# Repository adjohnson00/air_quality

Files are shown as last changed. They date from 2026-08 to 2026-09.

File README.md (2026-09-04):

# Air quality monitor

A local, battery-powered PM2.5 monitor for fire season in the Boise / Meridian, Idaho area. It sits on a shelf or windowsill, reads wildfire smoke from a Plantower laser sensor, and shows **US EPA AQI** on a sunlight-readable e-ink screen. There is no phone app and no cloud — the display is the product.

Summer haze here is usually fine particles from regional fires, not ozone or traffic. The number that matters is **PM2.5**. This build tracks that, plus PM1.0 / PM10 and particle counts, then sleeps so a small LiPo lasts days instead of hours.

**Approximate parts cost: ~$100** (Adafruit list prices, August 2026).

| [Hardware](#hardware) | [How it works](#how-it-works) | [Firmware](#firmware) |
| --- | --- | --- |

## Why this stack

- **Local.** Works during a power-adjacent smoke week without Wi‑Fi, Adafruit IO, or a phone.
- **Readable outdoors.** E-ink stays up with the power off and is usable in daylight, unlike a tiny OLED.
- **Low power.** The sensor’s fan draws ~180 mA from the battery while running. The firmware warms it up, takes a median of three samples, then cuts power and deep-sleeps.
- **Mostly plug-and-play.** Feather + FeatherWing stack, STEMMA QT for the sensor, LiPo that tucks under the headers.

Indoor / porch is the v1 goal. A sealed outdoor box would starve the laser sensor of air.

## Hardware

All parts are sold by Adafruit. The STEMMA cable is the **100 mm** length — long enough to exit the Feather / wing sandwich and leave the sensor sitting beside the stack with its vents open.

| Qty | Part | Adafruit | Price |
| ---: | --- | ---: | ---: |
| 1 | [FeatherS3\[D\] ESP32-S3](https://www.adafruit.com/product/6399) (Unexpected Maker) | 6399 | $24.95 |
| 1 | [2.9" grayscale eInk FeatherWing](https://www.adafruit.com/product/4777) (SSD1680) | 4777 | $22.50 |
| 1 | [PMSA003I air quality breakout](https://www.adafruit.com/product/4632) | 4632 | $44.95 |
| 1 | [STEMMA QT / Qwiic cable, 100 mm](https://www.adafruit.com/product/4210) | 4210 | $0.95 |
| 1 | [400 mAh LiPo, Feather-sized](https://www.adafruit.com/product/3898) | 3898 | $6.95 |
|  | **Total** |  | **$100.30** |

Prices are Adafruit’s single-unit list. Shipping, tax, and a USB-C data cable are extra.

### FeatherS3[D] — brains and power

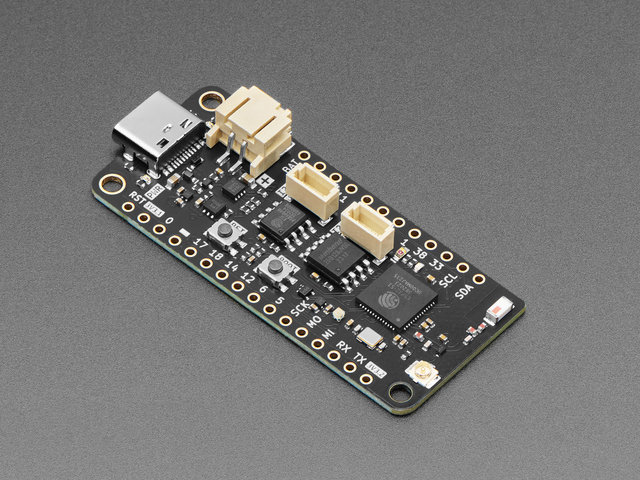
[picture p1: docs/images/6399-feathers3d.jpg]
FeatherS3[D] ESP32-S3 (https://www.adafruit.com/product/6399)


[Adafruit #6399](https://www.adafruit.com/product/6399) · [docs](docs/6399-feathers3d/)

Unexpected Maker’s ESP32-S3 Feather. Dual 240 MHz cores, 16 MB flash, 8 MB PSRAM, USB-C, LiPo charging, and a MAX17048 fuel gauge. Two STEMMA QT ports: **I2C1** stays up in deep sleep (fuel gauge), **I2C2** is on LDO2 so the air sensor can be powered down. The 400 mAh cell sits in the header well under the wing.

### 2.9" grayscale eInk FeatherWing — the screen

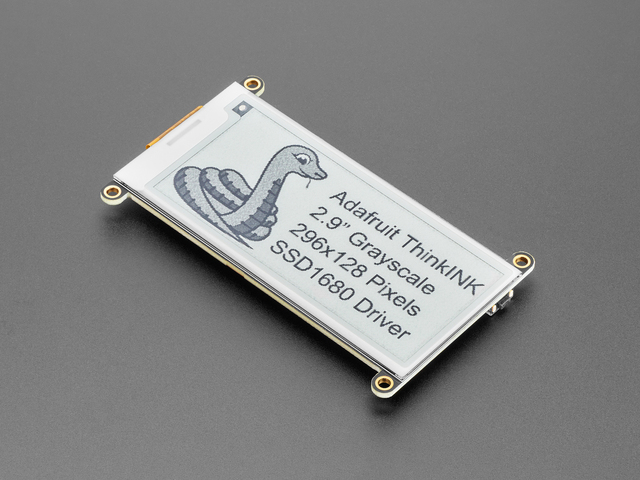
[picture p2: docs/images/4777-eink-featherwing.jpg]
2.9" grayscale eInk FeatherWing (https://www.adafruit.com/product/4777)


[Adafruit #4777](https://www.adafruit.com/product/4777) · [docs](docs/4777-eink-featherwing/)

296×128, four gray levels, SSD1680 (not the old IL0373). Image stays with the power off. On USB the firmware samples every 30 seconds and only refreshes the panel when the numbers change. Three buttons on the **back** of the wing (left to right from the back):

- **A** — force a sample now
- **B** — flip between the AQI card and particle-count bins immediately (press B again to go back)
- **C** — BLE pairing window (hold ~1.5 s to unpair)
- **Reset** — reboots the Feather

### PMSA003I — the smoke sensor

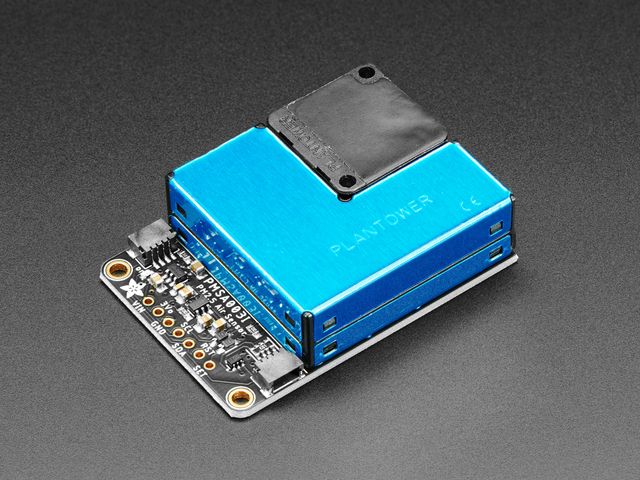
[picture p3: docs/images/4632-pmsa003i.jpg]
PMSA003I air quality breakout (https://www.adafruit.com/product/4632)


[Adafruit #4632](https://www.adafruit.com/product/4632) · [docs](docs/4632-pmsa003i/)

Plantower laser scatter module on a STEMMA QT breakout (I2C `0x12`). Reports PM1.0 / PM2.5 / PM10 and counts from 0.3–10 µm. The breakout boosts 3.3 V up to the 5 V the fan and laser need. This is a hobby sensor, not an FEM — treat it as a trend next to AirNow / PurpleAir, not a regulatory number.

### STEMMA QT cable, 100 mm

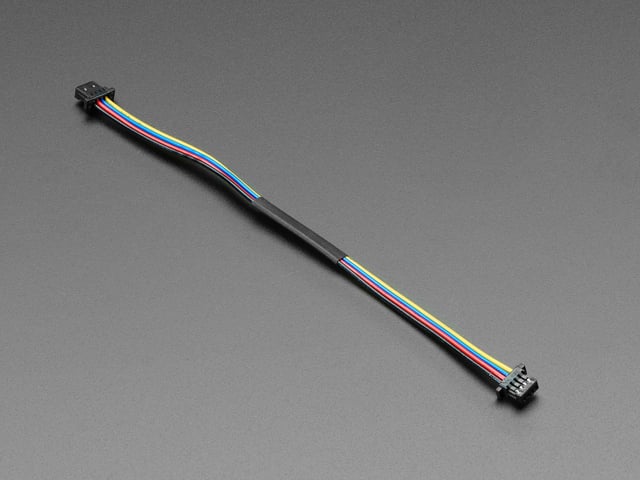
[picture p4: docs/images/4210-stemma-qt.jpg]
STEMMA QT 100 mm cable (https://www.adafruit.com/product/4210)


[Adafruit #4210](https://www.adafruit.com/product/4210) · [docs](docs/4210-stemma-qt-100mm/)

4-pin JST-SH, both ends the same. Plug it into **I2C2 (near USB) before stacking the wing** — that jack is not on the long header. 100 mm is long enough to route out the battery gap and park the sensor beside the stack.

### 400 mAh LiPo

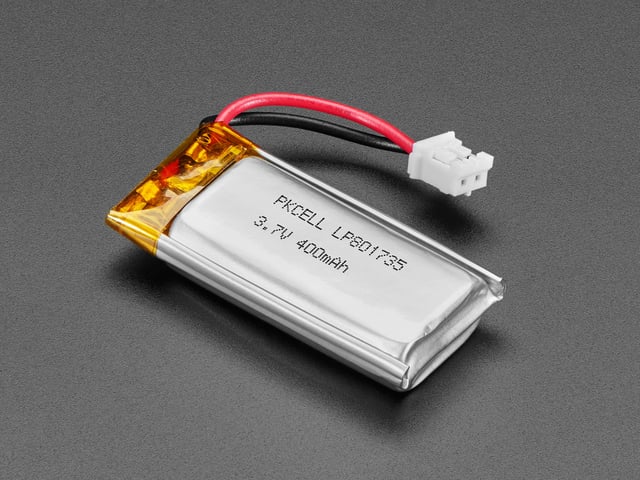
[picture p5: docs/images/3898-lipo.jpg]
400 mAh Feather LiPo (https://www.adafruit.com/product/3898)


[Adafruit #3898](https://www.adafruit.com/product/3898) · [docs](docs/3898-lipo-400mah/)

3.7 V, Feather-sized, 25 mm JST-PH. Charges from the Feather’s USB-C. A full cell is about **4.2 V**. With USB and no pack, the charger node floats ~4.0–4.3 V and SOC can read over 100% — the firmware shows `USB no batt` instead.

You do **not** need to leave USB + battery plugged in for the gauge to work. Powering down and unplugging the cell when idle is the right thing. Next boot, the MAX17048 estimates % from open-circuit voltage (quick-start). That is plenty for this display. A full charge/discharge “learn” cycle only tightens it; it is optional and not worth leaving the project on the charger unused.

At 15-minute samples the pack should last on the order of 3–5 days. Charge only via the Feather, and don’t puncture or bend it.

## How it works

Every sample the Feather enables **LDO2** (the 3.3 V rail on STEMMA I2C2), waits ~15 s for the PMSA003I fan, reads three frames, and keeps the median. If the sample interval is under 60 s (USB default 30 s), LDO2 stays on so you are not paying warmup every time. At 5 minutes or the 15-minute battery interval, LDO2 drops between reads and the sensor is fully off. PM2.5 (environmental) is converted with the **2024 US EPA AQI breakpoints** — same scale AirNow and Idaho DEQ use — as an instantaneous value, not 24-hour NowCast.

To sleep the sensor on USB too, set `USB_SAMPLE_INTERVAL_S = 300` in `settings.toml` (5 minutes).

The 2.9" card shows a large AQI number and category, a 4-gray bar, then PM1.0 / PM2.5 / PM10 in µg/m³ plus battery and USB status.

| Power | Sample interval | What it does |
| --- | --- | --- |
| USB-C | 60 seconds | Stays awake; LDO2 off between samples |
| Battery | 60 seconds, 5 s warmup | Sleeps between samples (`SLEEP_MODE`); ~8–13% sensor duty |
| Cell ≤ 3.2 V | Halt | LOW BATT card, **deep** sleep until USB (or 1 h recheck) |

Wi-Fi stays off. Bluetooth is off at boot and in sleep. The advertised name is always **`AQ-monitor`**. Press **C** to open a pairing window. A successful authorized `GET` (see `BLE_PIN`) marks the phone as paired; then the board advertises briefly on a schedule so you can pull the log without pressing C. Long-press **C** to unpair. Periodic advertising costs pack life — set `BLE_PERIODIC_S = 0` to advertise only after samples / C.

`SLEEP_MODE` in `settings.toml`:

- `"deep"` (default) — lowest current; `code.py` restarts each wake
- `"light"` — CPU paused, RAM kept, faster wake, more sleep current (tens of mA vs µA)
- `"no"` — CPU stays awake; LDO2/sensor on only for each sample (stays on if the interval is under 30 s)
- `"full"` — CPU and PMSA003I/LDO2 stay on

Each sample appends one row to `CIRCUITPY/data/voltN.csv` (voltage, %, USB, PM1/2.5/10, particle bins). A new number is used on each power-up / USB reload; older files are kept. Copy `data/` off the drive into this repo’s `data/` folder. Set `VOLTAGE_LOG = 0` to disable.

CircuitPython cannot write CIRCUITPY while the Mac has it mounted as a normal disk. `boot.py` remounts the drive **MCU-writable** (Finder shows it read-only — you can still copy logs off). **Hold A at reset** when you need to copy firmware onto the board.

## Docs in this repo

- [docs/firmware-loop.html](docs/firmware-loop.html) — how the main loop, sensing, and BLE fit together (open in a browser)
- [docs/project.md](docs/project.md) — original BOM notes
- [docs/build-plan.md](docs/build-plan.md) — pin map, power budget, firmware phases
- [hardware/assembly.md](hardware/assembly.md) — how to stack the boards
- [hardware/enclosure/](hardware/enclosure/) — 3D-printed case, rev 2 (1" stack, battery cage, RP-SMA, split airflow)
- [docs/](docs/) — datasheets and Adafruit learn guides

## Firmware

CircuitPython on the FeatherS3[D]. Source is in [`firmware/`](firmware/).

### Libraries

With the board mounted as `CIRCUITPY`:

```bash
pip install circup
circup install adafruit_pm25 adafruit_epd adafruit_max1704x adafruit_register neopixel adafruit_ble
```

Copy `firmware/font5x8.bin` to the root of `CIRCUITPY`. The e-ink text routines need it.

### Install

1. Assemble the stack ([hardware/assembly.md](hardware/assembly.md)).
2. Copy `firmware/bringup.py` to `CIRCUITPY/code.py` and confirm I2C addresses in the serial console (`0x36` on I2C1, `0x12` on I2C2).
3. Copy the rest of `firmware/` onto `CIRCUITPY` (`code.py`, the `.py` modules, `settings.toml`, `font5x8.bin`).
4. The board resets and draws the AQI card.

### Tests (no hardware)

```bash
python3 -m unittest tests.test_aqi tests.test_battery tests.test_vlog tests.test_ble_xfer
```

### BLE log dump (iPhone)

Uses [Bluefruit LE Connect](https://learn.adafruit.com/bluefruit-le-connect) (central mode).

1. `circup install adafruit_ble` (hold **A** at reset to copy files). Without that library, C shows `FAIL` on the card.
2. Press **C** anytime, including during sensor warmup (the 30 s wait runs in the main loop, so buttons and BLE still work). Footer shows `PAIR`. Connect to **`AQ-monitor`**, open **UART**, send `GET`. The UART session stays up until the phone disconnects; the board only polls `connected`. After a successful GET it stays awake and advertising (sensor/LDO2 off between samples) so you can reconnect without pressing C. Long-press **C** to unpair and return to `SLEEP_MODE`.
3. Send `GET` (or `GET yourpin` if `BLE_PIN` is set). Wait until `# AQ END` — a long log takes tens of seconds (20-byte BLE notifies). Copy after that; missing commas or a file that stops mid-line means it was still sending.
4. After a successful GET, the board can advertise on a schedule so you can reconnect without pressing C. Long-press **C** to unpair. Keep UART in the foreground.

Do not pair the board in iOS Settings. USB copy of `/data/` is still the bulk path. Set `BLE_PIN` on the device only (not in git) if you do not want a nearby phone to dump the log with a plain `GET`.

The FeatherS3[D] has an onboard 3D antenna **and** a u.FL jack, selected by GPIO41. Firmware drives that pin **low** so the onboard antenna is used (`BLE_ANTENNA = "internal"`). A floating switch can dump TX into the empty u.FL and show up on the phone as about **−95 dBm**. Advertising TX power is `BLE_TX_POWER` (default **9 dBm**); CircuitPython’s `BLERadio` helper otherwise always advertises at 0 dBm. You do not need an external antenna yet. If RSSI stays in the −90s after a copy/reset, check that nothing metal covers the 3D antenna; then try `BLE_TX_POWER = 20`. Only then set `BLE_ANTENNA = "external"` with a 2.4 GHz whip on the u.FL — transmitting into an open u.FL can stress the PA.

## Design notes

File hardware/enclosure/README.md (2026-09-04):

# 3D-printed enclosure (rev 2)

Two-piece FDM case. Display faces up. RP-SMA antenna bulkhead on the **left**. PMSA003I on the **floor** to the right, 2" axis away from the display. I/O channels stay at the **top** of the display. **No USB hole** — the Feather’s USB-C faces the AQI bay; plug in with the lid off.

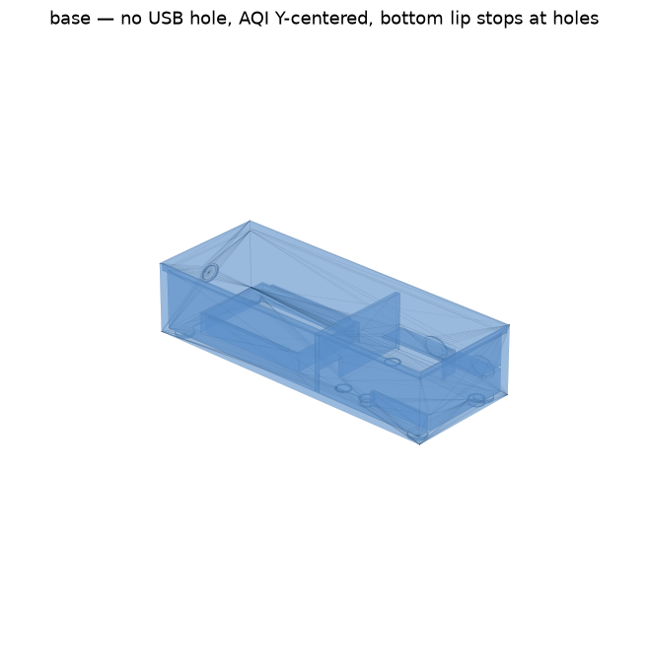
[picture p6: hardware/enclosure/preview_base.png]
Base


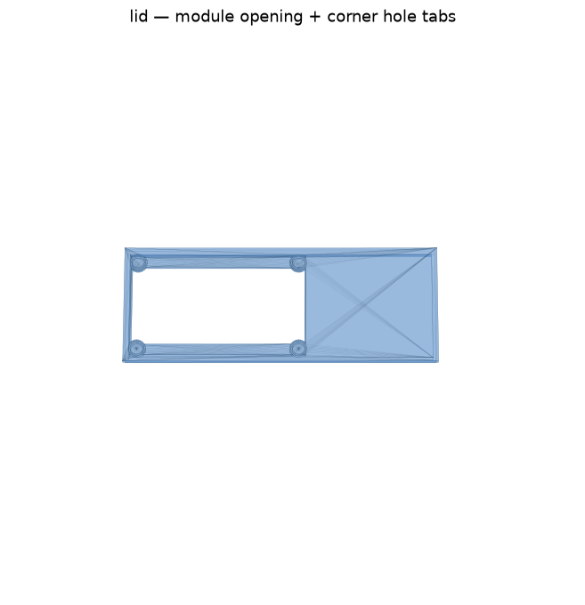
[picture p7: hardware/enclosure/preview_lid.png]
Lid


Outside is about **145 × 56 × 45 mm**.

```
  TOP (+Y)     intake ○ | ○ exhaust     (divider 7/8" from the far end)
               ─────────┴─────────
  LEFT (-X)    [RP-SMA]  [ 2.9" eInk ]  [ PMSA003I, Y-centered on display ]
  BOTTOM (-Y)  closed; AQI lip stops short of the two bottom holes (STEMMA)
  UNDER STACK            [ battery cage, 1/2" ]
```

| File | What |
| --- | --- |
| [aq_enclosure_base.stl](aq_enclosure_base.stl) | Battery cage, SMA pad, floor-mount AQI, intake/exhaust divider, 9/16" channel lips |
| [aq_enclosure_lid.stl](aq_enclosure_lid.stl) | Opening is the 79 × 36.7 mm e-ink module; corner tabs hold the four holes |
| [generate.py](generate.py) | Parametric generator |

## What changed vs rev 1

- Stack is **1"** (Feather + eInk). Battery is **not** in the sandwich. USB-C faces the AQI bay; use it with the lid off.
- Battery lives in a **low-lipped cage** under the stack: pack is **2.00" × 1-5/16" × 3/8"**, cage interior **52.8 × 35.3 × 12.7 mm** (about 2 mm of rattle room, 1/2" height).
- **Lid mounts the display.** Opening is the **e-ink module** (79.0 × 36.7 mm), not just the glass. The four M2.5 holes sit inside that rectangle on the long axis, so the lid keeps **corner tabs** to screw through. Same four pads work two ways:
  - **Inside** the lid → module in the opening, buttons hidden
  - **Outside** the lid → wing sits in the outer pocket, buttons reachable
- **RP-SMA** (uFL pigtail, threaded barrel) on the left end. Printed **solid** with a raised ring; drill 6.5 mm after printing.
- **No printed through-holes.** Wing, sensor, SMA, and air ports are filled pads at wall thickness with a raised ring as a drill guide.
- Sensor sits **on the floor** of the right-hand bay, **centered top-to-bottom on the display**. The 2" axis points away from the display (header toward the partition, can at the far wall). Two corner holes sit on the **top** edge of the display; the third corner is on the **bottom** edge nearest the display. A short **freestanding lip** (battery-cage style) runs along the module’s bottom edge and stops before the two holes on that side so the STEMMA cable can reach the QT jack.
- A wall splits **intake** (toward the display, hole in the blue aluminum) from **exhaust** (fan, far end). The divider is on the top wall, **7/8" from the far end** (1-1/8" from the display side of the module). Each path ends at a raised ring — drill those after you confirm alignment. The module is **open on top**. A **9/16" lip** overlaps the can by about 3.5 mm and roofs the air channel out to the top wall.
- PMSA003I holes are **not** a 4-corner rectangle. Three sit in corners; one is on the output-side edge. The two header-end holes are open on the PCB (screw down from inside). The two under the can are marked with rings on the **outside of the floor** so you can drill from below and screw up.

## Display vs lid (Adafruit 4777 Eagle)

| | Size | Notes |
| --- | --- | --- |
| PCB | 79.38 × 46.99 mm (3.125" × 1.850") | FeatherWing outline |
| Mounting holes | 74.30 × 42.16 mm, M2.5, centered | Four corners |
| e-ink **module** (obstruction) | 79.0 × 36.7 mm | Almost full PCB length |
| Glass (active) | ~67.0 × 29 mm, shifted ~2.8 mm along the long axis | Inside the module |
| Hole vs module | **inside** the 79 mm length by ~2.2 mm; **outside** the 36.7 mm width by ~2.7 mm | Corner tabs |

The lid opening is the module. Corner tabs put the screw pads back so the holes are not cut away.

## Drill later

| Mark | Size | Where |
| --- | --- | --- |
| 4 rings on the lid | 2.5 mm | eInk FeatherWing corners |
| 2 rings on the sensor floor (inside) | 2.5 mm | PMSA003I header-end holes (open on the PCB; screw down from above) |
| 2 rings on the sensor floor (**outside**) | 2.5 mm | PMSA003I holes under the can (screw up from below) |
| 1 ring on the left wall | 6.5 mm | RP-SMA bulkhead |
| 2 rings on the top wall | ~8–10 mm | intake (left of the divider) and exhaust (right, fan) |

## Print

| Setting | Value |
| --- | --- |
| Material | PLA; PETG if it will sit in a hot car |
| Layer | 0.20 mm |
| Walls | 3 |
| Infill | 20% gyroid |
| Supports | **On for the base** — normal or tree, from the bed. They fill the intake/exhaust ducts and catch the 3.5 mm overhang onto the can. Pull them before the sensor goes in. Lid: none. |
| Base | floor down (feet on the bed) |
| Lid | **outer face / window on the bed** so the outside pocket is smooth |

Lid lip is 0.35 mm undersize (`FIT`). Sand if tight.

## Assembly

1. Drop the pack into the cage under the display bay, JST toward USB.
2. uFL pigtail on the Feather; RP-SMA barrel waits until you drill the left pad.
3. STEMMA into I2C2, cable through the partition notch, along the open stretch of the AQI bottom lip (before the two holes), into the QT jack on the bottom edge of the PMSA003I.
4. **Inside mount:** seat the wing in the inner lid pocket, glass in the window, screw after drilling. Buttons face the battery cage.
5. **Outside mount:** seat the wing in the outer lid pocket, glass facing out, buttons on the back of the wing in the open. Screw after drilling.
6. PMSA003I on the right-hand **floor**, header toward the display, can toward the far wall. Two corner holes on the top edge; third corner at the bottom nearest the display. Fan toward the **top-right** (far) port, blue intake hole toward the **top-left** (display-side) port. Screw the two header-end holes from inside; drill the two under-can holes from the outside and screw up. The small 9/16" lips should rest on the +Y edge of the can and cover the air channels; the rest of the module stays open. Snap the lid on.
7. Drill intake and exhaust only after a dry fit so the holes line up with the fan and the aluminum inlet. Do not let those two volumes mix.

## Regenerating

```bash
.venv/bin/python hardware/enclosure/generate.py
```

| Knob | Default | Meaning |
| --- | --- | --- |
| `BAT_L` / `BAT_W` | 52.8 / 35.3 | Cage inside, mm (2.00" × 1-5/16" pack + clearance) |
| `BAT_CAGE_H` | 12.7 | 1/2" |
| `STACK_H` | 25.4 | 1" electronics |
| `RIDGE_H` | 14.3 | 9/16" lip height above the floor |
| `CHANNEL_LIP` | 3.5 | how far that lip sits onto the can, mm |
| `DIV_FROM_FAR` | 22.2 | 7/8" — intake/exhaust divider from the far end |
| `SMA_Z` | cage + 10 | Height of the SMA pad |
| `FIT` | 0.35 | Lid looseness |

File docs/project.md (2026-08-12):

**Final Project Summary**

### What you want it to do
You want a **local, battery-powered air quality monitor** for fire season in the Boise/Meridian, Idaho area. The main goal is to track particulate matter (especially PM2.5 from wildfire smoke) using the Adafruit PMSA003I laser sensor.  

Key requirements that emerged:
- ESP32-based (upgraded to S3 for better performance and PSRAM)
- E-ink display for low power and outdoor readability
- Battery powered with charging support
- Prefer an all-Adafruit (or Adafruit-sold) parts list for simplicity and support
- Plug-and-play STEMMA QT connections where possible

### Final Recommended Hardware (BOM)

| Qty | Item | Adafruit ID | Price |
|-----|---|---|---|
| 1 | **FeatherS3[D] ESP32-S3** (Unexpected Maker) | 6399 | $24.95 |
| 1 | **2.9" Grayscale eInk FeatherWing** | 4777 | $22.50 |
| 1 | **PMSA003I Air Quality Breakout** | 4632 | $44.95 |
| 1 | **STEMMA QT cable** (100 mm) | 4210 | $0.95 |
| 1 | **400 mAh LiPo battery** (Feather-sized) | 3898 | $6.95 |

**Approximate total: ~$100**

### Key design notes
- The FeatherS3[D] gives you 8 MB PSRAM, dual STEMMA QT ports, built-in LiPo charging + fuel gauge, and full FeatherWing compatibility.
- The 2.9" grayscale e-ink display stacks directly on top and stays readable in sunlight while drawing almost no power when static.
- The PMSA003I plugs in via STEMMA QT and reports PM1.0 / PM2.5 / PM10 + particle counts.
- The 400 mAh battery tucks under the stack and charges when USB-C is connected.

This setup prioritizes low power, outdoor usability, and straightforward assembly for monitoring Idaho wildfire smoke.

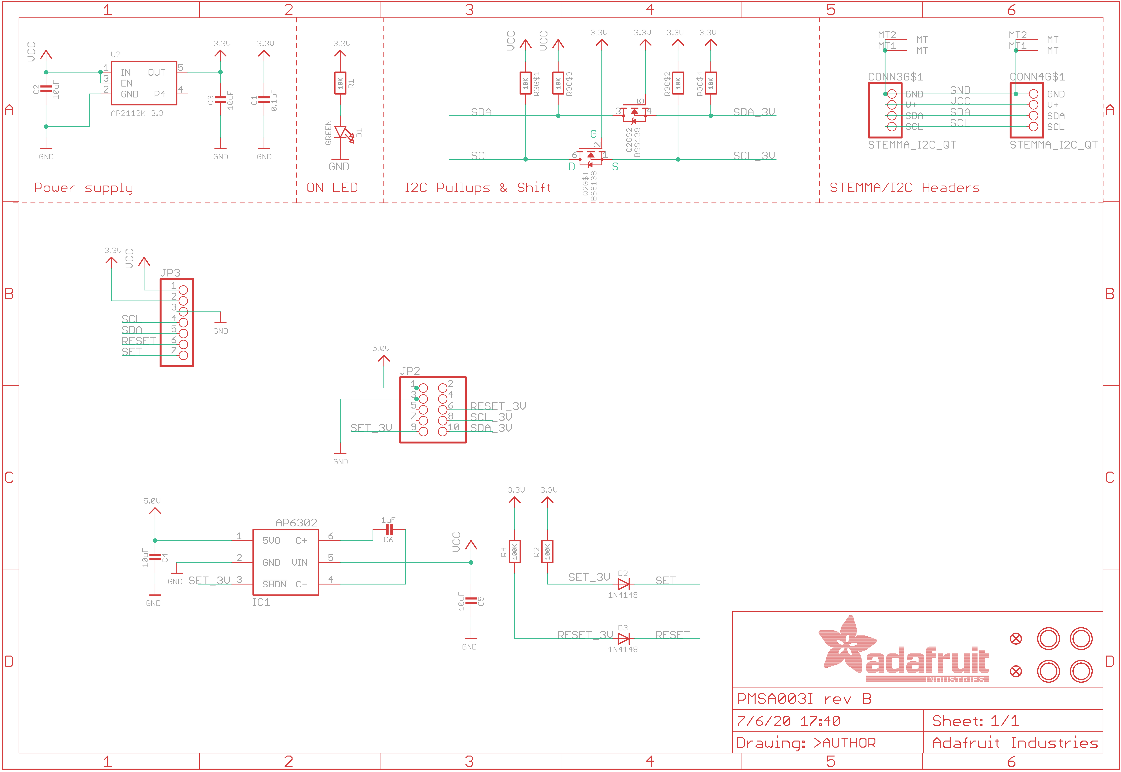
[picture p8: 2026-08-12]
docs/4632-pmsa003i/pmsa003i-schematic.png

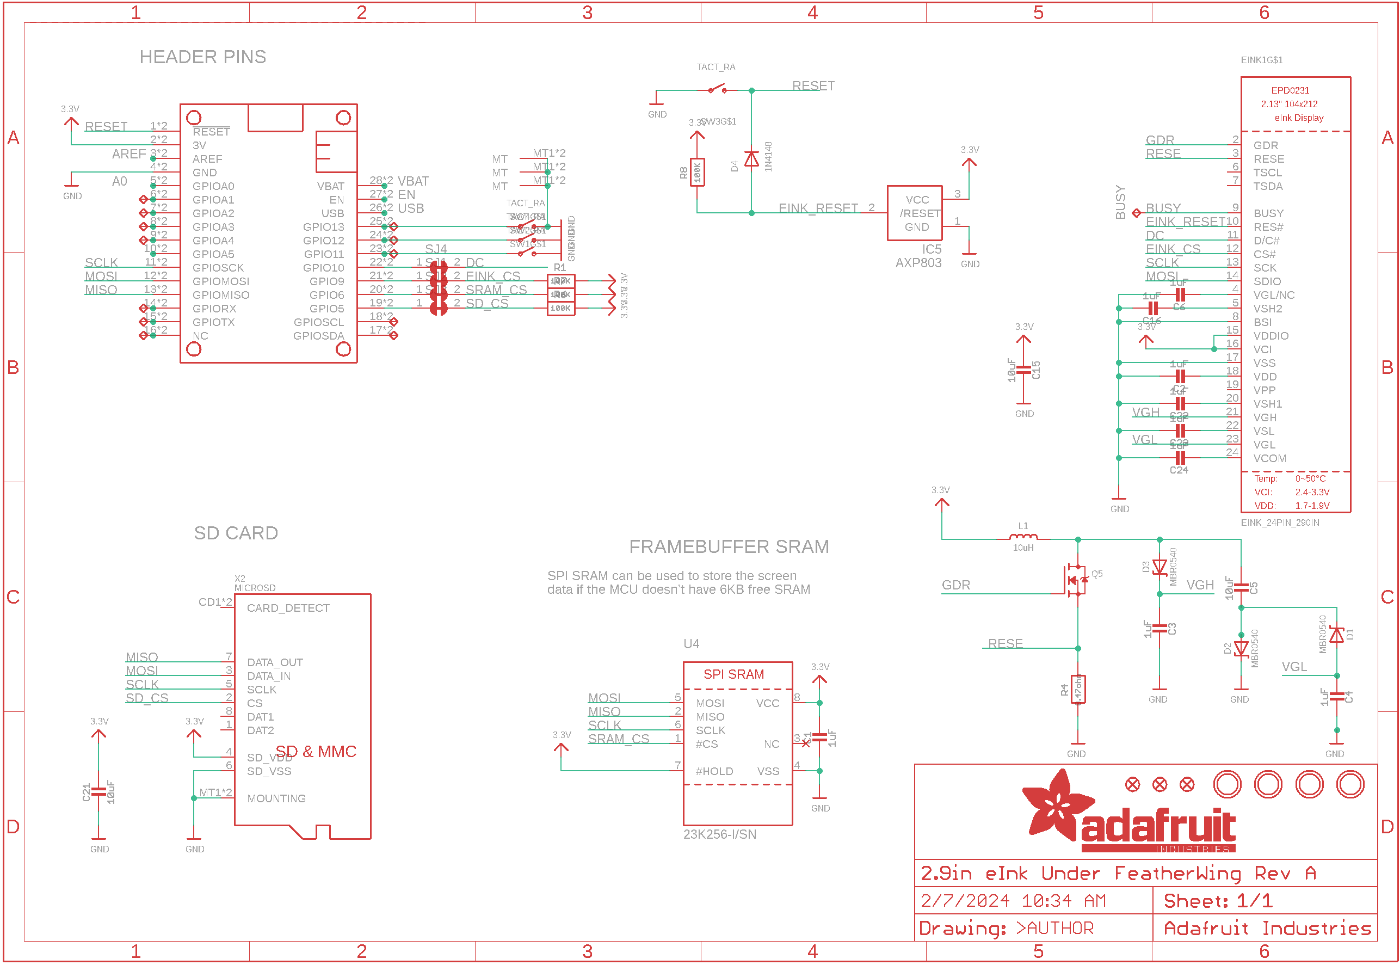
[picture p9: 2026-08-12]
docs/4777-eink-featherwing/featherwing-schematic.png

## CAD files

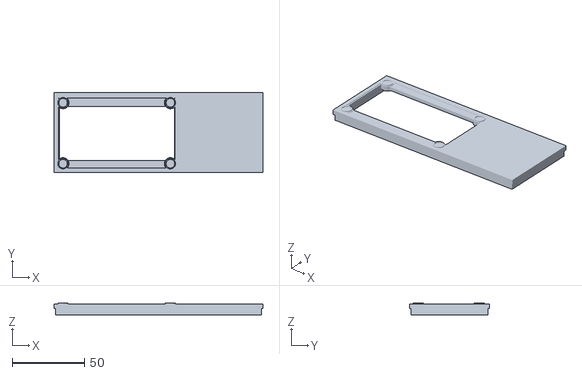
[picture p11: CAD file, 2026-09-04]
hardware/enclosure/aq_enclosure_lid.stl
144.6 x 55.4 x 8.20

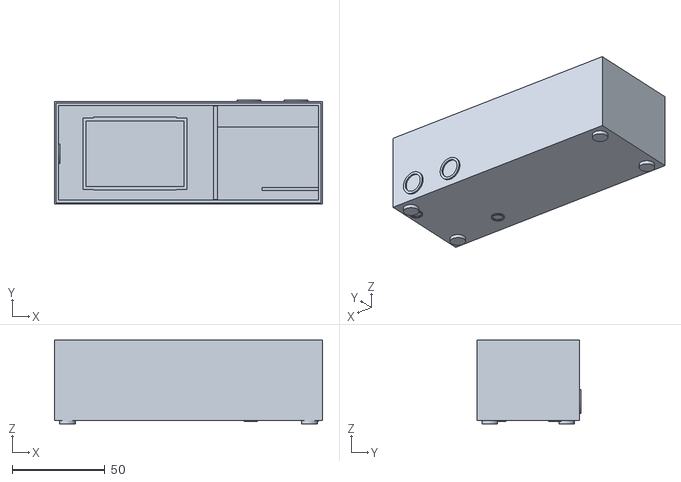
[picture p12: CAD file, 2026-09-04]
hardware/enclosure/aq_enclosure_base.stl
144.6 x 56.2 x 45.2

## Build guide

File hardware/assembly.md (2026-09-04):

# Assembly

No soldering if the eInk FeatherWing already has socket headers.

1. Update CircuitPython from [circuitpython.org](https://circuitpython.org/downloads?q=unexpected+maker+feathers3) if the shipping build is old. In the REPL, `dir(board)` should include `I2C2`, `LDO2`, and `D9`.
2. Plug the **100 mm** STEMMA cable into **I2C2** (the jack nearer USB) **before** stacking the wing. I2C2 is not on the long header.
3. Check LiPo polarity against the JST-PH silkscreen. Seat the 400 mAh cell in the header well. Use the wing’s normal-height sockets, not shorty headers.
4. Stack the eInk FeatherWing. Route the STEMMA cable out the side through the battery gap.
5. Leave the PMSA003I **beside** the stack with the fan vents open. Do not sandwich it.
6. First power-on from a USB-C **data** cable, battery connected.

Then copy `firmware/bringup.py` to `CIRCUITPY/code.py` and watch the serial console:

- I2C1 should list `0x36` (MAX17048)
- I2C2 should list `0x12` (PMSA003I)

Charge only via the Feather. Do not leave charging unattended for long. Do not puncture or bend the LiPo.

A 3D-printed two-piece case (battery corral, display window, sensor bay) is in [enclosure/](enclosure/). USB-C is lid-off only.

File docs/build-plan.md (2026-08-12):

# Air Quality Monitor — Project Plan

A local, battery-powered PM2.5 monitor for Boise / Meridian fire season. Hardware is the Adafruit-sold stack in `docs/project.md`. This plan turns that BOM into a working device: assemble it, bring up each chip, then ship a duty-cycled CircuitPython firmware that shows US EPA AQI on the e-ink panel.

## Goal

On a shelf or windowsill, the stack should:

- Read PM1.0 / PM2.5 / PM10 from the PMSA003I
- Convert PM2.5 to **US EPA AQI (2024 breakpoints)**
- Show a large AQI number, category, PM2.5 µg/m³, and battery % on the 2.9" grayscale e-ink
- Sleep between samples so the 400 mAh cell lasts days, not hours
- Charge from USB-C and stay usable while plugged in

No cloud, no phone app in v1. The screen is the product.

## Hardware map (do this first, it constrains everything)

```
                    USB-C
                      │
              ┌───────┴────────┐
              │  FeatherS3[D]  │  I2C1 (LDO1, always on): MAX17048 fuel gauge
              │                │  I2C2 (LDO2, IO39): PMSA003I via STEMMA
              │  400 mAh LiPo  │  sandwiched in the header well
              │      under     │
              ├────────────────┤
              │ 2.9" eInk Wing │  SPI: SCK/MOSI/MISO
              │  SSD1680 4-gray│  CS=D9  DC=D10  SRAM CS=D6 (optional)
              │  buttons A/B/C │  RST = Feather RESET (not a GPIO)
              └────────────────┘     BUSY not connected
                       │
              STEMMA 100 mm ──► PMSA003I sitting beside the stack
                                 (fan must have free air)
```

### Pins (CircuitPython names on Unexpected Maker FeatherS3)

| Function | Feather pin | GPIO | Notes |
|---|---|---|---|
| eInk CS | `board.D9` | IO1 | Official #4777 SSD1680 example |
| eInk DC | `board.D10` | IO3 | |
| eInk SRAM CS | `board.D6` | IO38 | Can pass `None` and use onboard RAM |
| eInk SD CS | `board.D5` | IO33 | Unused in v1 |
| eInk RST / BUSY | — | — | RST tied to Feather RESET. BUSY not routed. `busy_pin=None`, never `power_down()` the panel |
| Button A / B / C | `D11` / `D12` / `D13` | IO7 / IO10 / IO11 | |
| I2C1 SDA/SCL | `board.SDA` / `SCL` | IO8 / IO9 | Fuel gauge. `board.I2C()` |
| I2C2 SDA/SCL | `board.SDA2` / `SCL2` | IO16 / IO15 | Sensor. `board.I2C2` / `board.STEMMA_I2C2` |
| LDO2 enable | `board.LDO2` | IO39 | Shared with NeoPixel power. High = I2C2 STEMMA powered |
| VBUS sense | `board.VBUS` | IO34 | USB plugged in |
| Fuel gauge | MAX17048 on I2C1 | addr 0x36 | **Do not** read `board.VBAT` analog — on [D] that pin is the gauge INT |
| PMSA003I | I2C 0x12 | — | 100 kHz. Fan + laser need ~5 V; the breakout boosts from 3.3 V |

I2C2 exists only on the on-board STEMMA jack, not on the long header. Plug the STEMMA cable into **I2C2 (the connector nearer USB)** *before* stacking the wing. The battery creates ~8 mm of gap so the cable can exit the side.

### Power budget (why the firmware must sleep)

PMSA003I active current is ≤ 100 mA at 5 V. Through the 3.3 V boost that is roughly **170–200 mA from the LiPo** while the fan is spinning. Continuous run time on 400 mAh is about **2 hours**.

Recommended duty cycle:

| State | Time | Draw (order of mag.) |
|---|---|---|
| Sensor warmup + 3 samples | 15 s | ~180 mA |
| eInk refresh | ~3 s | ~80 mA |
| Deep sleep | 15 min − that | tens–hundreds of µA |

≈ 0.8–1.2 mAh per cycle → **about 3–5 days** at 15 minutes. On USB, skip sleep and sample every 3 minutes (eInk’s documented minimum refresh interval is 180 s; faster risks damaging the film).

Do **not** leave the sensor on I2C1. I2C1 stays powered in deep sleep (fuel gauge lives there). I2C2 + LDO2 cuts the sensor completely when the chip sleeps.

## Firmware decisions

1. **CircuitPython**, not Arduino. The board ships with it; Adafruit already has `adafruit_pm25`, `adafruit_epd` (SSD1680 4-gray), and `adafruit_max1704x`.
2. **`adafruit_epd.Adafruit_SSD1680_Grayscale4`**, not the old `adafruit_il0373` driver. July 2025 boards use SSD1680. Follow [feather_epd_grayscale_2in9_4777.py](https://github.com/adafruit/Adafruit_CircuitPython_EPD/blob/main/examples/feather_epd_grayscale_2in9_4777.py): `vcom=0x24`, rotation 3, subclass `power_down()` as a no-op.
3. **US EPA PM2.5 AQI, 2024 breakpoints** (AirNow / Idaho DEQ use this). Label the screen **AQI** but treat it as instantaneous concentration, not 24-hour NowCast, until we have hourly history.

   | PM2.5 µg/m³ | AQI | Category |
   |---|---|---|
   | 0.0 – 9.0 | 0 – 50 | Good |
   | 9.1 – 35.4 | 51 – 100 | Moderate |
   | 35.5 – 55.4 | 101 – 150 | USG |
   | 55.5 – 125.4 | 151 – 200 | Unhealthy |
   | 125.5 – 225.4 | 201 – 300 | Very Unhealthy |
   | 225.5 – 325.4 | 301 – 500 | Hazardous |

   Use **environmental** (`pm25 env`) values from the sensor.

4. **Refresh the panel only when it matters**: category change, PM2.5 delta ≥ 2 µg/m³, or at least once per hour. Saves eInk life and wake time.
5. **v1 is indoor / porch, local-only.** Outdoor enclosure, rain hood, and WiFi logging are explicit later work. The laser sensor needs a clear intake; a sealed box will lie.

## Assembly (one sitting, no soldering if the wing has sockets)

1. Update CircuitPython from [circuitpython.org](https://circuitpython.org/downloads?q=unexpected+maker) if the shipping build is old. Confirm `board.I2C2`, `board.LDO2`, `board.D9` exist (`dir(board)` in the REPL).
2. Identify **I2C2** on the Feather (near USB). Plug the **100 mm** STEMMA cable there.
3. Check LiPo polarity against the JST-PH silkscreen. Seat the 400 mAh cell in the header well. Use the wing’s **normal-height** sockets, not shorty headers.
4. Stack the eInk FeatherWing. Route the STEMMA cable out the side through the battery gap.
5. Leave the PMSA003I **beside** the stack, vents unobstructed. Do not sandwich it.
6. First power-on from **USB-C data** (not charge-only) with the battery connected so the charger and fuel gauge can be verified.

LiPo rules from the Adafruit docs: charge only via the Feather, never unattended for long, never puncture/bend, 400 mA max charge.

## Software architecture

```
firmware/
  code.py              # boot: USB vs battery path, sample loop or deep-sleep
  settings.toml        # SAMPLE_INTERVAL_S, SENSOR_WARMUP_S, refresh thresholds
  aqi.py               # EPA 2024 PM2.5 breakpoints + category colors/labels
  sensor.py            # LDO2 on → warmup → median of 3 reads → LDO2 off
  battery.py           # MAX17048 percent + voltage; VBUS detect
  display_ui.py        # 296×128 4-gray card
  power.py             # alarm deep sleep; pin alarms for buttons
  lib/                 # circup-installed Adafruit libs (gitignored)
```

`code.py` loop (battery):

1. Enable `board.LDO2`.
2. Sleep `SENSOR_WARMUP_S` (default 15).
3. `PM25_I2C(board.I2C2, reset_pin=None)` at 100 kHz. Median of 3 `read()` calls. On checksum error, retry twice then show last-good + a stale flag.
4. Read MAX17048 on `board.I2C()`.
5. `aqi.from_pm25(env)`.
6. If refresh needed → draw card → `display.display()`.
7. Drive `LDO2` low. `alarm.exit_and_deep_sleep_until_alarms(TimeAlarm, optional button PinAlarm)`.

USB (`board.VBUS` high): same sample/draw path, no deep sleep, 180 s interval, serial logging on. This is also the development mode.

### Display card (296×128, landscape)

```
┌──────────────────────────────────────────┐
│  85            MODERATE                  │
│  ████████████░░░░░░░░░░░░                │  4-gray AQI bar
│  PM2.5  28 µg/m³                         │
│  PM10 41    73%    15m ago               │
└──────────────────────────────────────────┘
```

- Page A (default): AQI + PM2.5
- Page B (button B): particle bins 0.3–10 µm
- Button A: force sample + refresh
- Button C: reserved (hold for settings later)

Four gray levels are the category language: black = this is serious, dark/light = mid, white = good. Do not try to fake AirNow’s green/yellow/red.

## Repo layout to create

```
firmware/          # CircuitPython app above
hardware/assembly.md
README.md          # what it is, how to flash, how to read the screen
docs/              # already present — leave as reference
```

Keep secrets out of git. `settings.toml` can live on `CIRCUITPY` and a `settings.toml.example` in the repo.

## Implementation phases

### Phase 0 — Repo and toolchain
Create the tree, `README`, `.gitignore` (`firmware/lib/`, `.DS_Store`). Document `circup install adafruit_pm25 adafruit_epd adafruit_max1704x`. Unit-test `aqi.py` on the host (pure math, no hardware).

### Phase 1 — Hardware bring-up (USB, no sleep)
Assemble per the steps above. REPL checklist:

- `board.I2C().scan()` → `0x36` (MAX17048)
- Enable LDO2, `board.I2C2.scan()` → `0x12` (PMSA003I)
- Feather RGB / blue LED blink so we know the board is alive

### Phase 2 — Sensor
`sensor.py` + serial print of env/standard PM and particle counts. Confirm warmup time empirically (datasheet total response ≤ 10 s; start at 15 s). Median-of-3 to ignore the first dirty sample after the fan spins up.

### Phase 3 — Display
Port the official SSD1680 4-gray FeatherWing example. Draw the AQI card with canned numbers. Confirm rotation, contrast (`vcom=0x24`), and that a refresh takes a few seconds. **Do not** call the driver’s `power_down()`.

### Phase 4 — Integrate live data
Wire sensor → AQI → display. Stale/error card if the sensor nacks. Show battery % from MAX17048.

### Phase 5 — Power management
Implement LDO2 gating and `alarm` deep sleep. Measure:

- USB current during warmup, during refresh, during sleep (USB meter or bench supply)
- Time-to-first-valid-sample after LDO2 on
- Overnight run on battery; confirm the image survives sleep

Tune `SENSOR_WARMUP_S` and `SAMPLE_INTERVAL_S` from that data. Default 15 min.

### Phase 6 — Buttons and polish
A = force sample, B = flip page. Persist last reading + hourly PM2.5 averages in NVM (`alarm.sleep_memory` or a small file) so a reset still has something to show. Optional: compute EPA NowCast once 12 hourly points exist.

### Phase 7 — Field check
Incense or a dusty walk as a smoke proxy. Compare the reading to AirNow / PurpleAir for the Boise area (expect a bias — this is a $45 Plantower, not an FEM). Verify sunlight readability and that the fan is not blocked in the real placement.

## Risks

| Risk | Mitigation |
|---|---|
| Wrong eInk driver (IL0373 vs SSD1680) | Use `Adafruit_SSD1680_Grayscale4`; blank/garbage screen means chipset mismatch |
| STEMMA jack buried under the wing | Cable I2C2 **before** stacking; 100 mm cable |
| 400 mAh dies in an afternoon | LDO2 duty cycle is mandatory; be honest about 3–5 day life |
| Sensor on I2C1 never powers down | I2C2 only |
| Checksum errors after power-gate | Warmup + retries; don’t draw a zero AQI on failure |
| eInk worn by 30 s updates | 180 s floor; skip refresh if the card would not change |
| FeatherS3 vs FeatherS3[D] pin confusion | `board.VBAT` analog is wrong on [D]; use MAX17048 |
| Outdoor rain / condensation | Out of scope for v1; do not seal the sensor |

## Out of scope for v1

- WiFi, Adafruit IO, MQTT, a web dashboard
- CO2 / VOC / humidity (no extra sensors on the BOM)
- Official NowCast as the primary number (needs 12 h of data first)
- 3D-printed outdoor enclosure
- A larger battery (easy later drop-in if 400 mAh is too short)

## What “done” looks like

USB-C plugged in: the panel shows a live AQI card that updates every 3 minutes, serial prints each sample, battery % climbs while charging.

Unplugged: the same card, updates every 15 minutes, survives overnight on the 400 mAh cell, wakes on button A.

That is the monitor. Everything else is a later revision.

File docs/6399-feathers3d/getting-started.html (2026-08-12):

Getting Started

## Congratulations!

If you are visiting this page, it’s likely you are a proud owner of a new Unexpected Maker ESP32-S3 board - congratulations!

We’ve put together this getting started guide to help you get familiar with your new ESP32-S3 board, and showcase some of the main features of the boards.

If you don’t already own a ESP32-S3 board from Unexpected Maker, you can buy one from here!

HOOKUP!
PLATFORMS
FLASHING CODE
BATTERY
HELPERS
KNOWLEDGE BASE (https://help.unexpectedmaker.com)

### Hooking it up!

All you need to do to get started is to plug your board into your computer using a USB-C Power + Data cable.

Your ESP32-S3 board ships with CircuitPython pre-installed and has some hello world code on it that runs when you power it up.

Once it starts up, you'll see a USB drive appear in your filesystem called CIRCUITPY and on the drive, you'll find a file named code.py that is currently running on your board. If you are new to CircuitPython, or would like to level up your CircuitPython skills, please check out Adafruit's Welcome to CircuitPython (https://learn.adafruit.com/welcome-to-circuitpython) learn guide.

### Coding Platforms

You are able to develop on your ESP32-S3 in a variety of languages and platforms.

Info for the most popular platforms, Espressif IDF, Arduino, CircuitPython and MicroPython are listed below, but other interesting languages are becoming available as well, like RUST (https://github.com/esp-rs/rust-build) and Go (TinyGO) (https://tinygo.org/docs/reference/microcontrollers/esp32-mini32/).

#### CitcuitPython

Shape (https://circuitpython.org/downloads?q=unexpected+maker+esp32s3)

#### Your board ships with the latest version of CircuitPython!

It also ships with the UF2 bootloader, so you can easily update your board with the latest CircuitPython firmware, whenever you desire.

Just plug your board into your computer and it will appear in your filesystem as a USB flash drive! Just copy your code over, or edit your code directly on the drive. Coding a microcontroller has never been easier!

As newer versions of CircuitPython are released, you are able to update to them as you require from circuitpython.org (https://circuitpython.org/downloads?q=unexpected+maker+esp32s3)

If you need to grab the shipping CircuitPython code that comes with your board,
you can grab the latest here (https://github.com/unexpectedmaker/esp32s3/)

#### MicroPython

Shape (https://micropython.org/download/?mcu=esp32s3&vendor=Unexpected%20Maker)

MicroPython has excellent support for the ESP32, and that includes the ESP32-S3.

If you would like to put MicroPython on your new board, please follow the flashing guide for your board from this firmware link (https://micropython.org/download/?mcu=esp32s3&vendor=Unexpected%20Maker) and don't forget to erase your flash first!

For more information about developing projects on your new board, using MicroPython, check out the MicroPython documentation (http://docs.micropython.org/en/latest/).

Regarding MicroPython, Please Note!

##### Unlike CircuitPython and the STM32 port of MicroPython, the ESP32 port of MicroPython does not present you with a Mass Storage Drive to add/copy/edit code.

It presents you with a USB serial port, and you need to use a tool like mpremote (https://docs.micropython.org/en/latest/reference/mpremote.html) to access the file system to add/copy/edit files.

#### Espressif IDF

Shape

ESP32-S3 support in the IDF is part of the v4.4 release. The latest IDF is v5.0, but it's in early development, so I recommend you stick to the v4.4 release branch for the time being as there are some low level breaking changes in v5.

Check out the ESP32-S3 IDF Docs (https://docs.espressif.com/projects/esp-idf/en/latest/esp32s3/index.html) for information on how to install it and develop for the ESP32-S3

#### Arduino IDE

Shape

Firstly, please make sure you have downloaded and installed (https://www.arduino.cc/en/software) the Arduino IDE for your OS if you have not already installed it.

Then, if you have not already setup your Arduino IDE environment to work with ESP32, or you are still on version 1.0.6 of the ESP32 Arduino Core, please follow the official Espressif ESP32 Arduino Core instructions (https://docs.espressif.com/projects/arduino-esp32/en/latest/installing.html) to install/update it.

Arduino support for the ESP32-S3 is available in the Espressif ESP32 Arduino Core 2.0.3 and later. Please install the latest version to be able to select ESP32-S3 boards with the latest fixes and features.

You can install this version from the Arduino IDE board manager (Image is the new Arduino IDE 2):
Shape
If you want to live on the bleeding edge, feel free to stay on the latest version by cloning this repo (https://github.com/espressif/arduino-esp32/) instead.

Shape Once the ESP32 boards support is installed, you can select your new board from the boards drop down list.

You are looking for UM TinyS3, UM ProS3 and UM FeatherS3.

#### PlatformIO

Shape

PlatformIO support is a bit fractures for Espressif MCUs right now. Official support stops at ESP32 Arduino Core 2.x, which is old now, but you can use the ESP32 Arduino Core 3.x by using the ESP32 Core provided by the PIOARDUINO (https://github.com/pioarduino/platform-espressif32). You replace

[env]
platform = platformio/espressif32

with

[env]	
platform = https://github.com/pioarduino/platform-espressif32/releases/download/stable/platform-espressif32.zip

When using the PlatformIO for development, you need to ensure you enabled the USB peripheral when your code runs, or you will not see a serial port to re-flash or get any serial output. To enable the USB peripheral, you need to add:

build_flags = 
-D ARDUINO_USB_CDC_ON_BOOT=1

Here’s an example of how to use an UM Feather S3 in platformIO. This is in the platformio.ini file:

[env]
platform = platformio/espressif32
board = um_feathers3
framework = arduino
; Waiting isn't needed for CDC/JTAG USB mode
board_upload.wait_for_upload_port = false 

lib_deps =
	Wire
	SPI
	; Add your other libraries here

build_flags =
	-D ARDUINO_USB_MODE=1 ; CDC/JTAG USB mode
	; Needed for USB to enumerate when user code starts
	-D ARDUINO_USB_CDC_ON_BOOT=1

I have a full PlatformIO example project for the FeatherS3 (https://github.com/UnexpectedMaker/esp32s3/tree/main/code/platformio/featherS3_example) on GitHub.
The example can be altered to work with any other UM board by changing the line

board = um_feathers3

To any other UM board.

#### NEW! nanoFramework

Shape

You can now use the amazing nanoFramework on your Unexpected Maker ESP32-S3 boards!

nanoFramework is an embedded version of the .NET framework, which allows you to develop in C# on your microcontroller - how cool is that!

Check out the nanoFramework website (https://www.nanoframework.net) for information on how to install it and develop for the ESP32-S3

### Flashing Code Onto Your Board

From time to time, you might want to try out different programming languages on your ESP32-S3 board, or you might just want to update the version of CircuitPython or MicroPython you are using. To achieve this, you'll need to learn how to put your board into different boot modes.

First time flashing you board?

Unexpected Maker ESP32-S3 boards ship with CircuitPython flashed on them. If you want to re-flash your board with the IDF or Arduino IDE, or even install MicroPython firmware, you have to put your board into DOWNLOAD mode for the first flash as the serial port you might see listed from CircuitPython is not able to be flashed directly.

#### Getting into DOWNLOAD Mode

Putting your board into Download Mode will force your board to restart in the CDC bootloader mode and enumerate a new serial device (COM port for Windows users). Form there you can flash the board using that serial port.

This mode is used to flash a new version of the UF2 bootloader, or a new version of MicroPython onto your board, or even to flash some IDF or Arduino Code, if you are not enabling the native USB on boot-up.

To get your board into Download mode:

- Press and hold the [BOOT] button down
- Press and Release the [RESET] button
- Release the [BOOT] button

There is no visual cue on the board that it is in Download mode, but you should now see a new serial device appear.

#### Getting into UF2 Bootloader Mode

Putting your board into UF2 Bootloader will force your board to restart and present you with a USB mass storage device in your file explorer - assuming you have the UF2 bootloader still installed and you have not stomped it by flashing Arduino, MicroPython or IDF code on the board.

All Unexpected maker ESP32-S3 boards ship with CircuitPython and the UF2 Bootloader installed by default.

To get your board into UF2 bootloader mode:

- Press and Release [RESET]
- When the RGB LED is turns purple, Press and Release [BOOT]

You should now be in the UF2 bootloader mode. You will then see the RGB LED on your board turn green once the filesystem is mounted.

#### Flashing in the Arduino IDE

When using the Arduino IDE for development, there are a few things you need to be aware of.

Shape The Unexpected Maker ESP32-S3 boards leverage the native USB inside the S3 chip and do not use an external SerialUART chip like older ESP32 boards did. This means you need to enable the CDC on boot option in the Arduino IDE tools menu to ensure the native USB is enabled when your code runs.

Please also select the USB OTG (TinyUSB) option and ensure you have selected the correct UM Board definition from the boards list:

##### UM Tinys3, UM FeatherS3 & UM ProS3

NOTE! There is a ROM Mask bug in the current ESP32-S3 silicon that prevents the flashing process from resetting the board after flashing has finished, which means for now, you need to manually press the [RESET] button after flashing to manually reset the board so your code start running. Updated silicon from Espressif will fix this issue hopefully!

### Powering From Battery

Your ESP32-S3 boards comes with support for using a battery to power your projects as well as the ability to charge your battery off the USB connector (or 5V pin if you are using an external 5V power supply).

The TinyS3 comes with a separate JST PH connector that you can solder onto the bottom of the board, as well as a VBAT header pin next to a GND pin to allow you to connect a battery via the headers.

The FeatherS3 and ProS3 come with a battery connector on the board. The FeatherS3 has a JST PH connector and the ProS3 has a PicoBlade connector. Both also a VBAT header pin next to a GND pin to allow you to connect a battery via the headers.

You can use any size, single cell Li-Po battery to power your ESP32-S3 boards. Obviously, the larger the mAH rating of the battery, the longer it will last.

Please use LiPo-Batteries with charge protection included on them. Most hobby RC batteries do not have over discharge protection, and if a battery discharges too much, it can damage it and it might never be able to hold a proper charge again.

NOTE: When connecting a battery to your ESP32-S3 board, please check the polarity of the battery, as not every battery is wired the same way. The IC I use for charging does have in-built reverse voltage protection, but it’s better not to tempt fate!

### Helper Libraries

I have put together helper libraries (https://github.com/UnexpectedMaker/esp32s3/tree/main/code) for CircuitPython, MicroPython & Arduino to help you access certain functions of your ESP32-S3 board in an easy way.

The Arduino Helper Library is downloaded from the library manager within the Arduino IDE. Please search for the library called UMS3 Helper

The MicroPython version of the helper is compiled into the firmware itself, where as the CircuitPython version is sitting in the filesystem on your board.

The included CircuitPython code that runs when your board powers up uses the helper library to do certain things, like cycle the RGB LED, turn the RGB LED power on (or the second LDO if the board is a FeatherS3 or ProS3) and it shows you how much Flash and RAM you have free.

You can also use the helper library to see if there is 5V power present:

import tinys3
print(f"5V present? {tinys3.get_vbus_present()}")

Or check the battery voltage if one is connected:

import tinys3
print(f"VBAT voltage is {tinys3.get_battery_voltage()}v")

For MicroPython or CircuitPython, use the tinys3.py, feathers3.py & pros3.py helper library for each board, and for Arduino, there's one helper library for all 3 boards.

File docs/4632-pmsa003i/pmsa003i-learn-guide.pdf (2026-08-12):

# Adafruit PMSA003I Air Quality Breakout

Created by Kattni Rembor

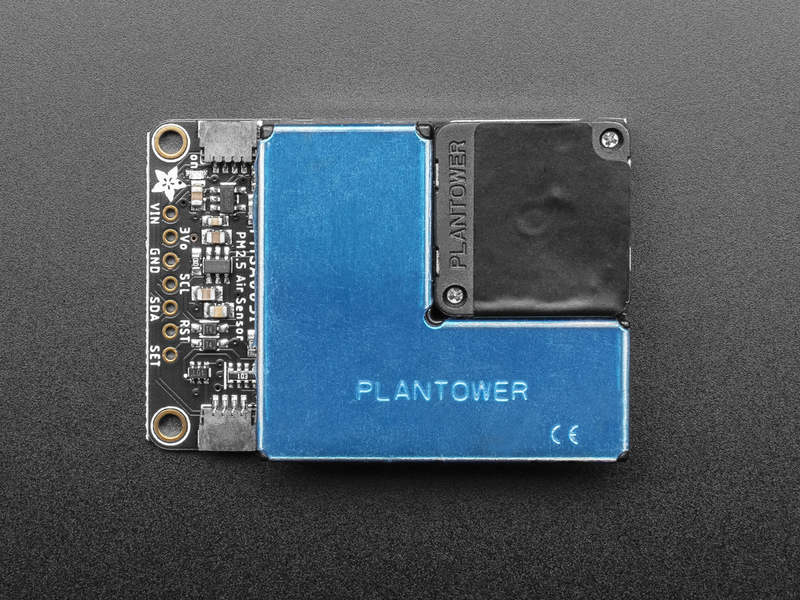
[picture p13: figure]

https://learn.adafruit.com/pmsa003i

Last updated on 2025-09-10 09:19:26 AM EDT

©Adafruit Industries | Page 1 of 25

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
## Table of Contents

Overview
Pinouts
- Power Pins
- I2C Logic Pins
- Other Pins
Arduino
- I2C Wiring
- Library Installation
- Load Example
- Example Code
Arduino Docs
Python & CircuitPython
- CircuitPython Microcontroller Wiring
- Python Computer Wiring
- CircuitPython Installation of PM25 Library
- Python Installation of PM25 Library
- CircuitPython & Python Usage
Python Docs
WipperSnapper Setup
- What is WipperSnapper
- Wiring
- Usage
Downloads
- Files
- Schematic
- Fab Print

# Overview

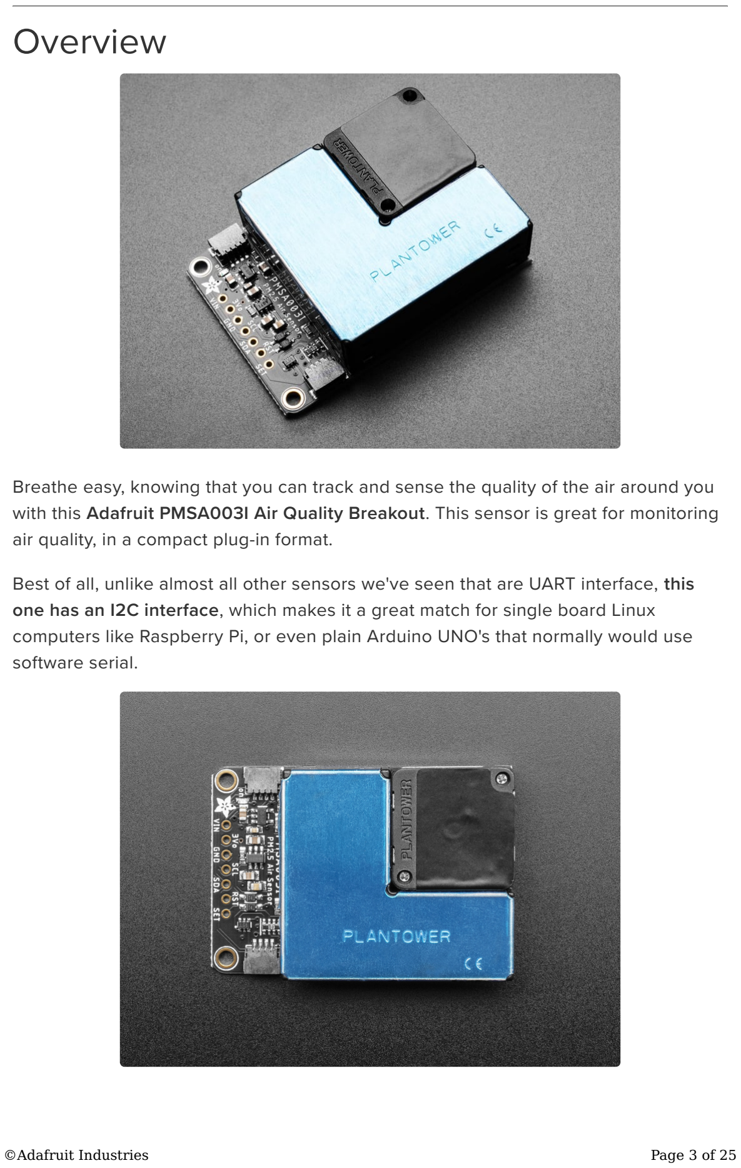
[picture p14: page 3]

Breathe easy, knowing that you can track and sense the quality of the air around you with this Adafruit PMSA003I Air Quality Breakout. This sensor is great for monitoring air quality, in a compact plug-in format.
Best of all, unlike almost all other sensors we've seen that are UART interface, this one has an I2C interface, which makes it a great match for single board Linux computers like Raspberry Pi, or even plain Arduino UNO's that normally would use software serial.

If you're an I2C fan (who isn't?), we've included two of our handy dandy SparkFun Qwiic (https://www.sparkfun.com/qwiic) (https://adafru.it/Fpw) compatible STEMMA QT (https://learn.adafruit.com/introducing-adafruit-stemma-qt) (https://adafru.it/Ft4) connectors for the I2C bus so you don't even need to solder! Plug and play with other 'QT boards and sensors to add quick air quality sensing.
This sensor uses laser scattering to radiate suspending particles in the air, then collects scattering light to obtain the curve of scattering light change with time. The microprocessor calculates equivalent particle diameter and the number of particles with different diameters per unit volume.
The I2C data stream updates once per second, you'll get:

PM1.0, PM2.5 and PM10.0 concentration in both standard & environmental units Particulate matter per 0.1L air, categorized into 0.3um, 0.5um, 1.0um, 2.5um, 5.0um and 10um size bins

As well as checksum, in binary format.

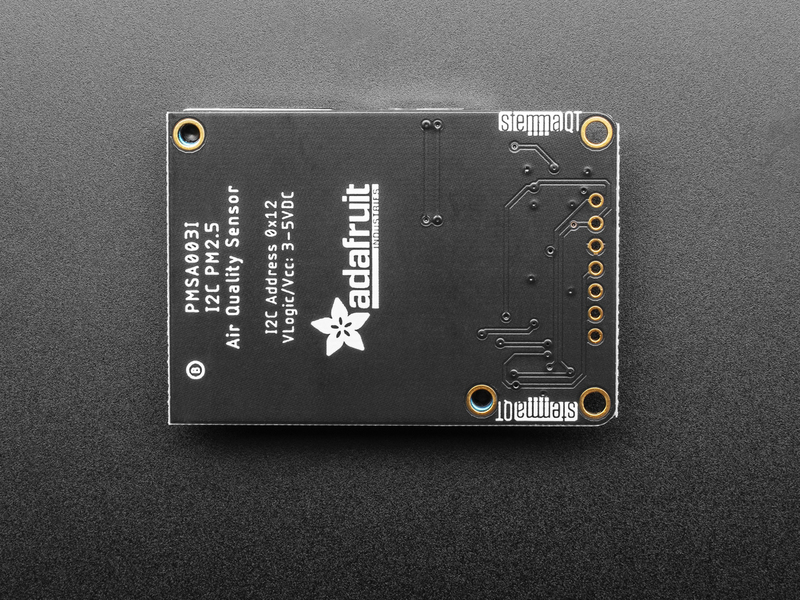
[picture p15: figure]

Each order comes with one fully assembled sensor module breakout, including some header if you'd like to solder it to a breadboard. The breakout board has a 5V mini boost circuit so you can power it from 3.3V and 5V and the motor fan inside the sensor will run just fine
Lastly, it wouldn't be an Adafruit breakout if it didn't come with libraries for Arduino (http://github.com/adafruit/Adafruit_PM25AQI) (https://adafru.it/Mb5) and CircuitPython & Python (http://github.com/adafruit/Adafruit_CircuitPython_PM25) (https://adafru.it/Mb6) that will read and checksum data, and print it out in human-readable format.

•
•

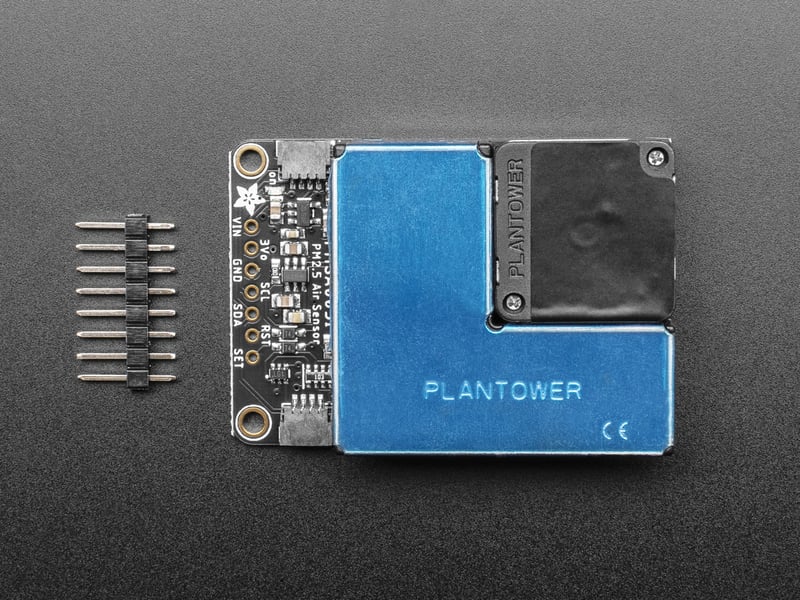
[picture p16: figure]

# Pinouts

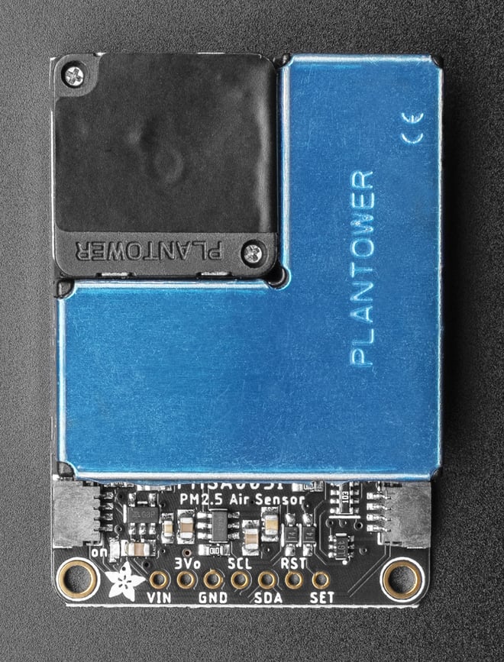
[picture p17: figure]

## Power Pins

Vin - this is the power pin. Since the sensor chip uses 3 VDC, we have included a voltage regulator on board that will take 3-5VDC and safely convert it down. To power the board, give it the same power as the logic level of your microcontroller - e.g. for a 5V microcontroller like Arduino, use 5V
3Vo - this is the 3.3V output from the voltage regulator, you can grab up to 100mA from this if you like
GND - common ground for power and logic

•

•

•

## I2C Logic Pins

SCL - I2C clock pin, connect to your microcontroller I2C clock line. On the breakouts, this pin is level shifted so you can use 3-5V logic. There's a 10K pullup on this pin.
SDA - I2C data pin, connect to your microcontroller I2C data line.
On the breakouts, this pin is level shifted so you can use 3-5V logic. There's a 10K pullup on this pin.
STEMMA QT (https://learn.adafruit.com/introducing-adafruit-stemma-qt) (https://adafru.it/Ft4) - These connectors allow you to make I2C connections to dev boards with STEMMA QT connectors or to other things with various associated accessories (https://www.adafruit.com/?q=JST%20SH%204) (https://adafru.it/Ft6).

## Other Pins

RST - Module signal reset. Reset low.
SET - Set pin. High when working status, low level is sleeping mode.

# Arduino

Using the PMSA300I with Arduino is a simple matter of wiring up it to your Arduino-compatible microcontroller, installing the Adafruit PM25AQI (https://github.com/adafruit/Adafruit_PM25AQI) (https://adafru.it/Mej) library we've written, and running the provided example code.

## I2C Wiring

Wiring the PMSA300I is made simple by using the I2C interface either via the STEMMA QT connector or a solderless breadboard.

•

•
•

•

•
•

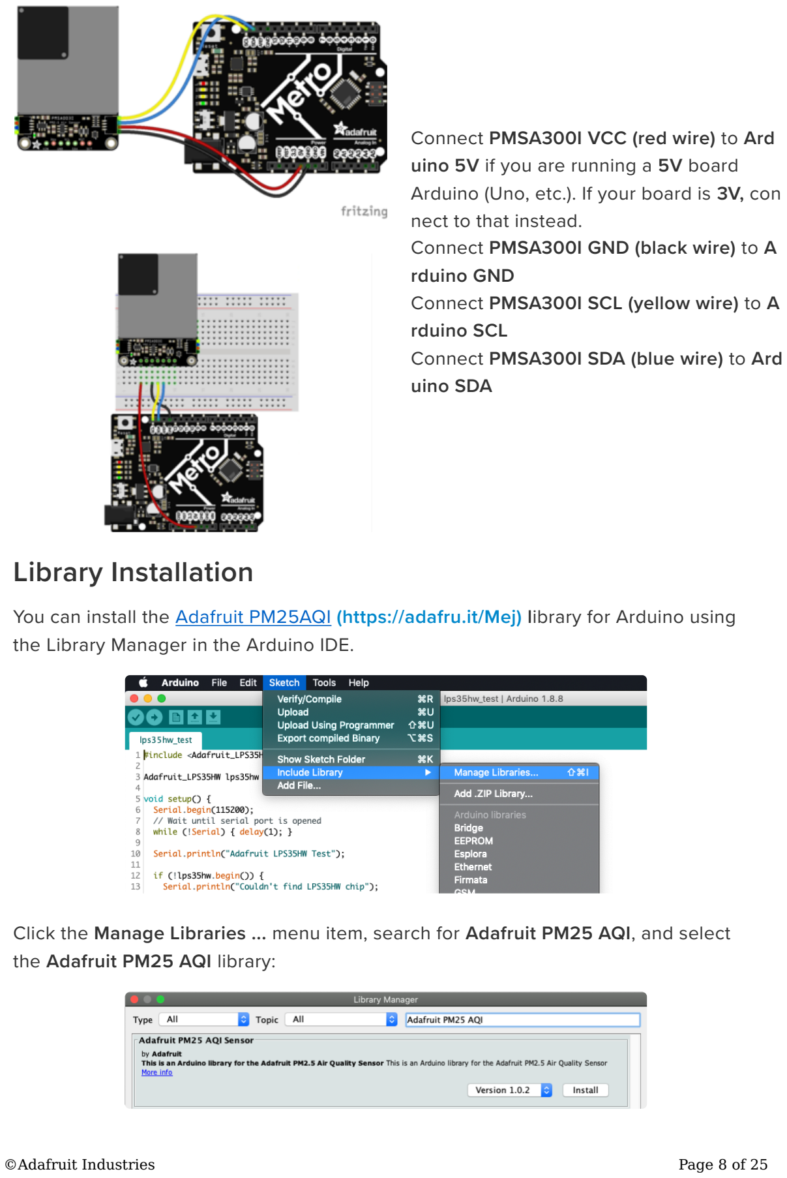
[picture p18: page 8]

Connect PMSA300I VCC (red wire) to Ard uino 5V if you are running a 5V board Arduino (Uno, etc.). If your board is 3V, con nect to that instead.
Connect PMSA300I GND (black wire) to A rduino GND
Connect PMSA300I SCL (yellow wire) to A rduino SCL
Connect PMSA300I SDA (blue wire) to Ard uino SDA

## Library Installation

You can install the Adafruit PM25AQI (https://github.com/adafruit/Adafruit_PM25AQI) (https://adafru.it/Mej) library for Arduino using the Library Manager in the Arduino IDE.

Click the Manage Libraries ... menu item, search for Adafruit PM25 AQI, and select the Adafruit PM25 AQI library:

Follow the same process for the Adafruit BusIO library.

## Load Example

Open up File -> Examples -> Adafruit PM25 AQI Sensor -> PM25_test
After opening the demo file, upload to your Arduino wired up to the sensor. Once you upload the code, you will see the air quality data being printed when you open the Serial Monitor (Tools->Serial Monitor) at 115200 baud, similar to this:

## Example Code

/* Test sketch for Adafruit PM2.5 sensor with UART or I2C */

#include "Adafruit_PM25AQI.h"

// If your PM2.5 is UART only, for UNO and others (without hardware serial) // we must use software serial...
// pin #2 is IN from sensor (TX pin on sensor), leave pin #3 disconnected // comment these two lines if using hardware serial
//#include <SoftwareSerial.h>
//SoftwareSerial pmSerial(2, 3);

Adafruit_PM25AQI aqi = Adafruit_PM25AQI();

void setup() {
// Wait for serial monitor to open Serial.begin(115200);

The United States standards for particulates by color changed in 2024. See this update (https://www.epa.gov/system/files/documents/2024-02/pm-naaqs-air-quality-index-fact-sheet.pdf) from the US EPA for the new standards.

while (!Serial) delay(10);

Serial.println("Adafruit PMSA003I Air Quality Sensor");

// Wait three seconds for sensor to boot up!
delay(3000);

// If using serial, initialize it and set baudrate before starting! // Uncomment one of the following
//Serial1.begin(9600);
//pmSerial.begin(9600);

// There are 3 options for connectivity!
if (! aqi.begin_I2C()) { | // connect to the sensor over I2C
//if (! aqi.begin_UART(&Serial1)) { // connect to the sensor over hardware serial //if (! aqi.begin_UART(&pmSerial)) { // connect to the sensor over software serial
Serial.println("Could not find PM 2.5 sensor!");
while (1) delay(10);
}

Serial.println("PM25 found!");
}

void loop() {
PM25_AQI_Data data;

if (! aqi.read(&data)) {
Serial.println("Could not read from AQI");

delay(500); // try again in a bit! return;
}
Serial.println("AQI reading success");

Serial.println(F("---------------------------------------")); Serial.println(F("Concentration Units (standard)")); Serial.print(F("PM 1.0: ")); Serial.print(data.pm10_standard); Serial.print(F("\t\tPM 2.5: ")); Serial.print(data.pm25_standard); Serial.print(F("\t\tPM 10: ")); Serial.println(data.pm100_standard); Serial.println(F("---------------------------------------")); Serial.println(F("Concentration Units (environmental)")); Serial.print(F("PM 1.0: ")); Serial.print(data.pm10_env); Serial.print(F("\t\tPM 2.5: ")); Serial.print(data.pm25_env); Serial.print(F("\t\tPM 10: ")); Serial.println(data.pm100_env); Serial.println(F("---------------------------------------")); Serial.print(F("Particles > 0.3um / 0.1L air:")); Serial.println(data.particles_03um);
Serial.print(F("Particles > 0.5um / 0.1L air:")); Serial.println(data.particles_05um); Serial.print(F("Particles > 1.0um / 0.1L air:")); Serial.println(data.particles_10um); Serial.print(F("Particles > 2.5um / 0.1L air:")); Serial.println(data.particles_25um); Serial.print(F("Particles > 5.0um / 0.1L air:")); Serial.println(data.particles_50um);
Serial.print(F("Particles > 10 um / 0.1L air:")); Serial.println(data.particles_100um); Serial.println(F("---------------------------------------")); Serial.println(F("AQI"));
Serial.print(F("PM2.5 AQI US: ")); Serial.print(data.aqi_pm25_us); Serial.print(F("\tPM10 AQI US: ")); Serial.println(data.aqi_pm100_us);
// Serial.print(F("PM2.5 AQI China: ")); Serial.print(data.aqi_pm25_china);
// Serial.print(F("\tPM10 AQI China: ")); Serial.println(data.aqi_pm100_china); Serial.println(F("---------------------------------------")); Serial.println();

delay(1000);
}

# Arduino Docs

Arduino Docs (https://adafruit.github.io/Adafruit_PM25AQI/html/index.html) (https://adafru.it/MdQ)

# Python & CircuitPython

It's easy to use the PMSA300I and the Adafruit CircuitPython PM25 (https://github.com/adafruit/Adafruit_CircuitPython_PM25) (https://adafru.it/Mek) module. This library allows you to easily write Python code that reads particle concentrations, and particle diameter and the number of particles with different diameters per unit volume.
You can use this sensor with any CircuitPython microcontroller board or with a computer that has GPIO and Python thanks to Adafruit_Blinka, our CircuitPython-for-Python compatibility library (https://learn.adafruit.com/circuitpython-on-raspberrypi-linux) (https://adafru.it/BSN).

## CircuitPython Microcontroller Wiring

Wire up a PMSA300I to your board exactly as shown below. Here's an example of wiring a Feather M4 to the sensor with I2C using STEMMA QT and a solderless breadboard.

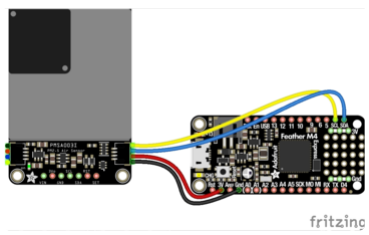
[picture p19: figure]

Board 3V to PMSA300I VIN (red wire) Board GND to PMSA300I GND (black wire)
Board SCL to PMSA300I SCL (yellow wire) Board SDA to PMSA300I SDA (blue wire)

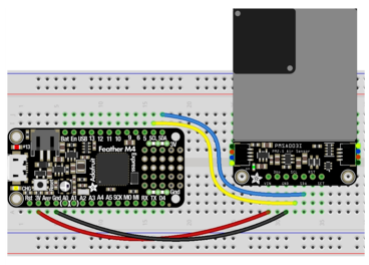
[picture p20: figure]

## Python Computer Wiring

Since there's dozens of Linux computers/boards you can use, we will show wiring for Raspberry Pi. For other platforms, please visit the guide for CircuitPython on Linux to see whether your platform is supported (https://learn.adafruit.com/circuitpython-on-raspberrypi-linux) (https://adafru.it/BSN).
Here's the Raspberry Pi wired to the sensor with I2C using STEMMA QT and a solderless breadboard.

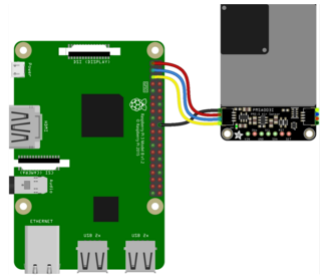
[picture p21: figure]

Pi 3V to PMSA300I VIN (red wire)
Pi GND to PMSA300I GND (black wire) Pi SCL to PMSA300I SCL (yellow wire) Pi SDA to PMSA300I SDA (blue wire)

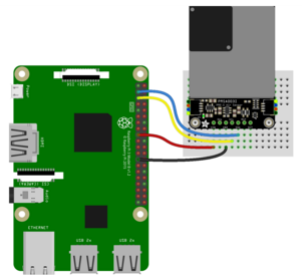
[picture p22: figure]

## CircuitPython Installation of PM25 Library

You'll need to install the Adafruit CircuitPython PM25 (https://github.com/adafruit/Adafruit_CircuitPython_PM25) (https://adafru.it/Mek) library on your CircuitPython board.
First make sure you are running the latest version of Adafruit CircuitPython (https://learn.adafruit.com/welcome-to-circuitpython/installing-circuitpython) (https://adafru.it/Amd) for your board.
Next you'll need to install the necessary libraries to use the hardware--carefully follow the steps to find and install these libraries from Adafruit's CircuitPython library bundle (https://circuitpython.org/libraries) (https://adafru.it/ENC).
Our CircuitPython starter guide has a great page on how to install libraries from the bundle (https://learn.adafruit.com/welcome-to-circuitpython/circuitpython-libraries) (https://adafru.it/ABU).
Load the the following libraries into the lib folder on your CIRCUITPY drive:

adafruit_pm25
adafruit_bus_device

•
•

Before continuing make sure your board's lib folder or root filesystem has the adafruit _pm25 file and adafruit_bus_device folder copied over.
Next connect to the board's serial console (https://learn.adafruit.com/welcome-to-circuitpython/kattni-connecting-to-the-serial-console) (https://adafru.it/Bec)so you are ready to see the example output.

## Python Installation of PM25 Library

You'll need to install the Adafruit_Blinka (https://github.com/adafruit/Adafruit_Blinka) (https://adafru.it/BJX) library that provides the CircuitPython support in Python. This may also require enabling I2C on your platform and verifying you are running Python 3.
Since each platform is a little different, and Linux changes often, please visit the CircuitPython on Linux guide to get your computer ready (https://learn.adafruit.com/circuitpython-on-raspberrypi-linux) (https://adafru.it/BSN)! Once that's done, from your command line run the following command:

pip3 install adafruit-circuitpython-pm25
If your default Python is version 3 you may need to run 'pip' instead. Just make sure you aren't trying to use CircuitPython on Python 2.x, it isn't supported!

## CircuitPython & Python Usage

To demonstrate the usage of the PMSA300I, we'll use a complete code example to read the particle data.
Save the following code to your CIRCUITPY drive as code.py:

# SPDX-FileCopyrightText: 2021 ladyada for Adafruit Industries

# SPDX-License-Identifier: MIT

"""
Example sketch to connect to PM2.5 sensor with either I2C or UART. """

import time

import board
import busio
from digitalio import DigitalInOut, Direction, Pull

from adafruit_pm25.i2c import PM25_I2C

reset_pin = None

The United States standards for particulates by color changed in 2024. See this update (https://www.epa.gov/system/files/documents/2024-02/pm-naaqs-air-quality-index-fact-sheet.pdf) from the US EPA for the new standards.

# If you have a GPIO, its not a bad idea to connect it to the RESET pin # reset_pin = DigitalInOut(board.G0)

# reset_pin.direction = Direction.OUTPUT

# reset_pin.value = False

# For use with a computer running Windows:

# import serial

# uart = serial.Serial("COM30", baudrate=9600, timeout=1)

# For use with microcontroller board:

# (Connect the sensor TX pin to the board/computer RX pin) # uart = busio.UART(board.TX, board.RX, baudrate=9600)

# For use with Raspberry Pi/Linux:

# import serial

# uart = serial.Serial("/dev/ttyS0", baudrate=9600, timeout=0.25)

# For use with USB-to-serial cable:

# import serial

# uart = serial.Serial("/dev/ttyUSB0", baudrate=9600, timeout=0.25)

# Connect to a PM2.5 sensor over UART

# from adafruit_pm25.uart import PM25_UART

# pm25 = PM25_UART(uart, reset_pin)

# Create library object, use 'slow' 100KHz frequency! i2c = busio.I2C(board.SCL, board.SDA, frequency=100000) # Connect to a PM2.5 sensor over I2C

pm25 = PM25_I2C(i2c, reset_pin)

print("Found PM2.5 sensor, reading data...")

while True:
time.sleep(1)

try:
aqdata = pm25.read()
# print(aqdata)

except RuntimeError:
print("Unable to read from sensor, retrying...") continue

print()
print("Concentration Units (standard)") print("---------------------------------------")
print(
"PM 1.0: %d\tPM2.5: %d\tPM10: %d"
% (aqdata["pm10 standard"], aqdata["pm25 standard"], aqdata["pm100 standard"])
)
print("Concentration Units (environmental)") print("---------------------------------------")
print(
"PM 1.0: %d\tPM2.5: %d\tPM10: %d"
% (aqdata["pm10 env"], aqdata["pm25 env"], aqdata["pm100 env"]) )
print("---------------------------------------")
print("Particles > 0.3um / 0.1L air:", aqdata["particles 03um"]) print("Particles > 0.5um / 0.1L air:", aqdata["particles 05um"]) print("Particles > 1.0um / 0.1L air:", aqdata["particles 10um"]) print("Particles > 2.5um / 0.1L air:", aqdata["particles 25um"]) print("Particles > 5.0um / 0.1L air:", aqdata["particles 50um"]) print("Particles > 10 um / 0.1L air:", aqdata["particles 100um"]) print("---------------------------------------")

If you haven't already, connect to the serial console to see the example output.

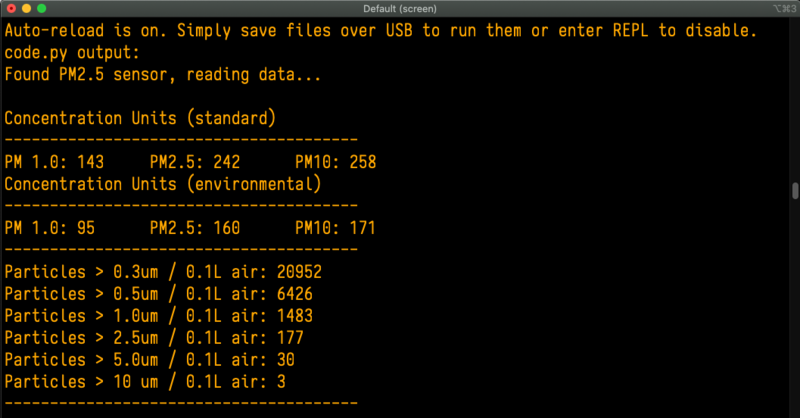
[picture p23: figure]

That's all there is to reading air quality data from the PSMA300I!

# Python Docs

Python Docs (https://circuitpython.readthedocs.io/projects/pm25/en/latest/) (https://adafru.it/MdP)

# WipperSnapper Setup

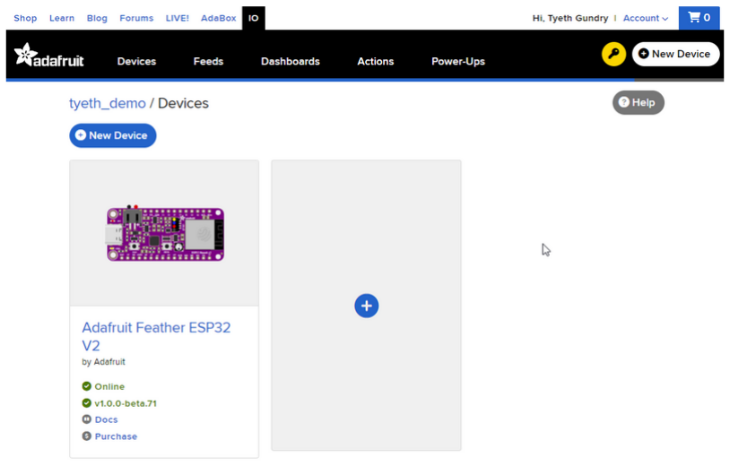
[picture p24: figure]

## What is WipperSnapper

WipperSnapper is a firmware designed to turn any WiFi-capable board into an Internet-of-Things device without programming a single line of code. WipperSnapper connects to Adafruit IO (https://io.adafruit.com/) (https://adafru.it/fsU), a web platform designed (by
Adafruit! (https://www.adafruit.com/about) (https://adafru.it/Bo5)) to display, respond, and interact with your project's data.
Simply load the WipperSnapper firmware onto your board, add credentials, and plug it into power. Your board will automatically register itself with your Adafruit IO account.

From there, you can add components to your board such as buttons, switches, potentiometers, sensors, and more! Components are dynamically added to hardware, so you can immediately start interacting, logging, and streaming the data your projects produce without writing code.
If you've never used WipperSnapper, click below to read through the quick start guide before continuing.
Quickstart: Adafruit IO
WipperSnapper (https://learn.adafruit.com/quickstart-adafruit-io-wippersnapper)
https://adafru.it/Vfd

## Wiring

First, wire up a PMSA003I to your board exactly as follows. Here is an example of the PMSA003I wired to an Adafruit ESP32 Feather V2 (https://www.adafruit.com/product/5400) (http://adafru.it/5400) using
I2C with a STEMMA QT cable (no soldering required) (https://www.adafruit.com/product/4210) (http://adafru.it/4210)

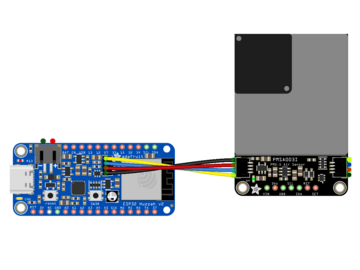
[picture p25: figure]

Board 3V to sensor VIN (red wire on STEMMA QT)
Board GND to sensor GND (black wire on STEMMA QT)
Board SCL to sensor SCL (yellow wire on STEMMA QT)
Board SDA to sensor SDA (blue wire on STEMMA QT)

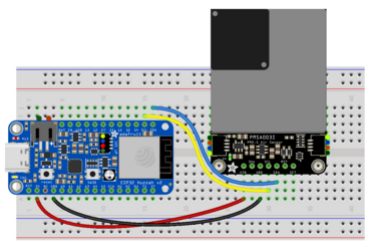
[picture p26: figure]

## Usage

Connect your board to Adafruit IO Wippersnapper and navigate to the WipperSnapper board list (https://io.adafruit.com/wippersnapper) (https://adafru.it/TAu).

On this page, select the WipperSnapper board you're using to be brought to the board's interface page.

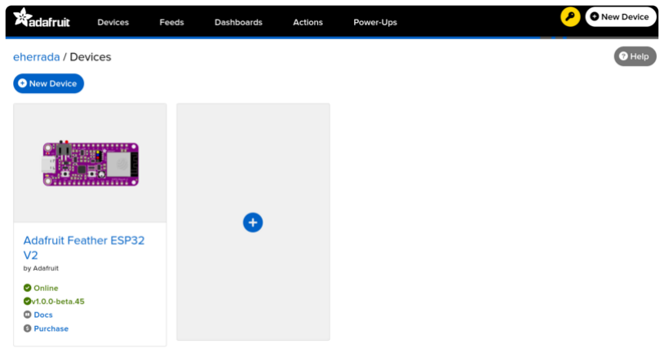
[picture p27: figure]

If you do not see your board listed here - you need to connect your board to Adafruit IO (https://learn.adafruit.com/quickstart-adafruit-io-wippersnapper) (https://adafru.it/Vfd) first.

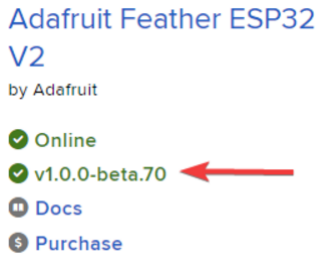
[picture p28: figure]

On the device page, quickly check that you're running the latest version of the WipperSnapper firmware.
The device tile on the left indicates the version number of the firmware running on the connected board.

If the firmware version is green with a checkmark - continue with this guide.
If the firmware version is red with an "X" -update to the latest WipperSnapper firmware (https://learn.adafruit.com/quickstart-adafruit-io-wippersnapper) (https://adafru.it/Vfd) on your board before continuing.

Next, make sure the sensor is plugged into your board and click the I2C Scan button.

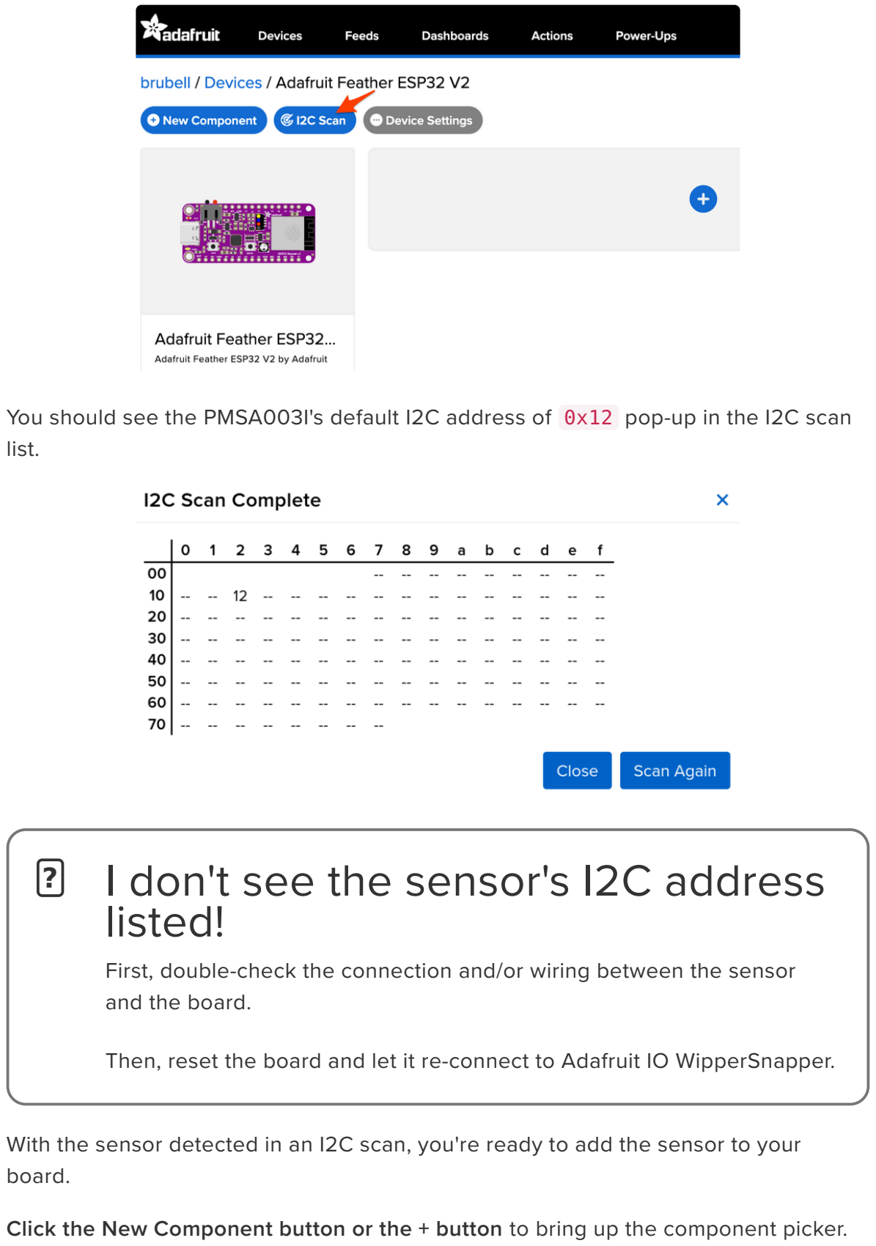
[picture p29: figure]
list.; board.; and the board.; I don't see the sensor's I2C address; listed!

You should see the PMSA003I's default I2C address of | 0x12 | pop-up in the I2C scan

With the sensor detected in an I2C scan, you're ready to add the sensor to your

Click the New Component button or the + button to bring up the component picker.

First, double-check the connection and/or wiring between the sensor

Then, reset the board and let it re-connect to Adafruit IO WipperSnapper.

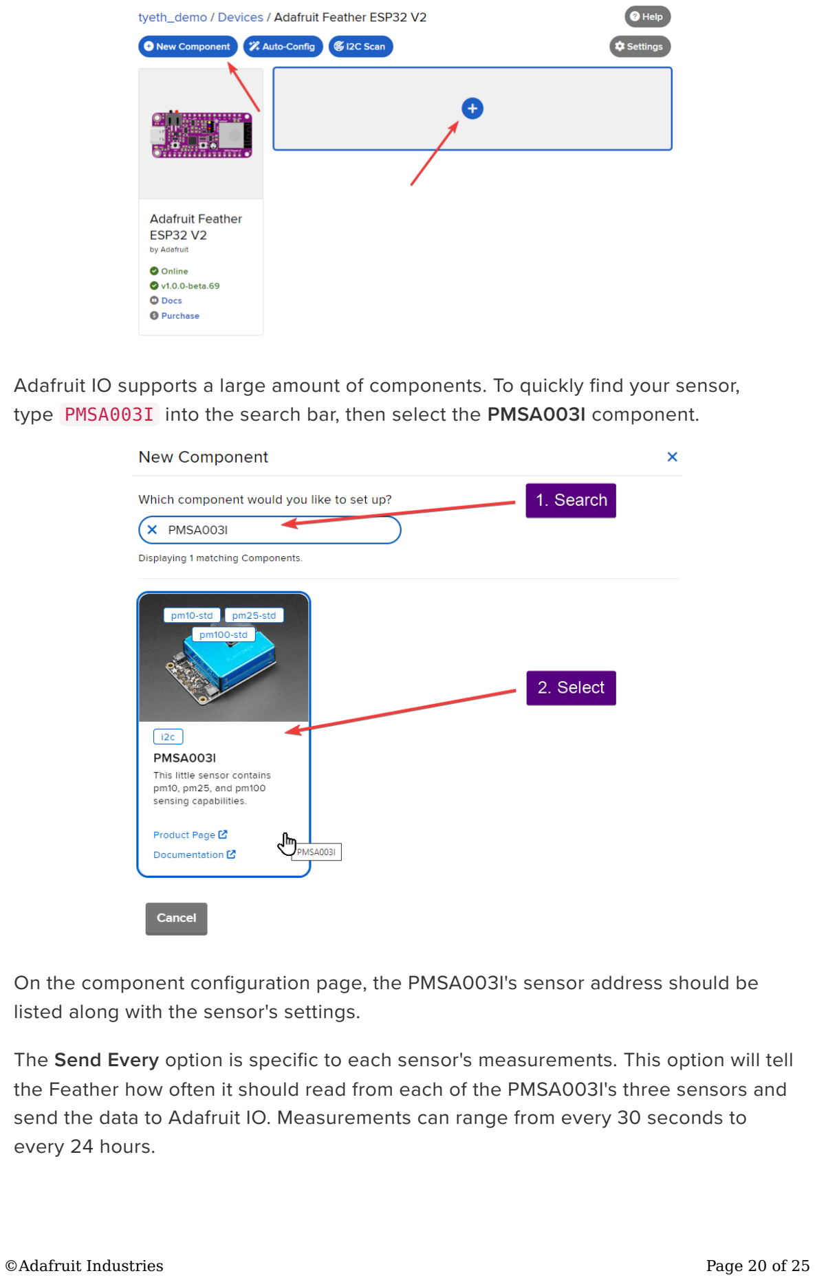
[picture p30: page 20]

Adafruit IO supports a large amount of components. To quickly find your sensor,
type | PMSA003I | into the search bar, then select the PMSA003I component.

On the component configuration page, the PMSA003I's sensor address should be listed along with the sensor's settings.
The Send Every option is specific to each sensor's measurements. This option will tell the Feather how often it should read from each of the PMSA003I's three sensors and send the data to Adafruit IO. Measurements can range from every 30 seconds to every 24 hours.

On WipperSnapper, the PMSA003I reports particulate matter PM1.0, PM2.5, and PM10.0 concentrations in standard units only. If you need particulate matter reported in environmental units or particulate matter categorized into 0.3um, 0.5um, 1.0um, 2.5um, 5.0um, and 10um size bins, use the CircuitPython or Arduino libraries.
For this example, set the Send Every interval for each sensor to every 30 seconds.

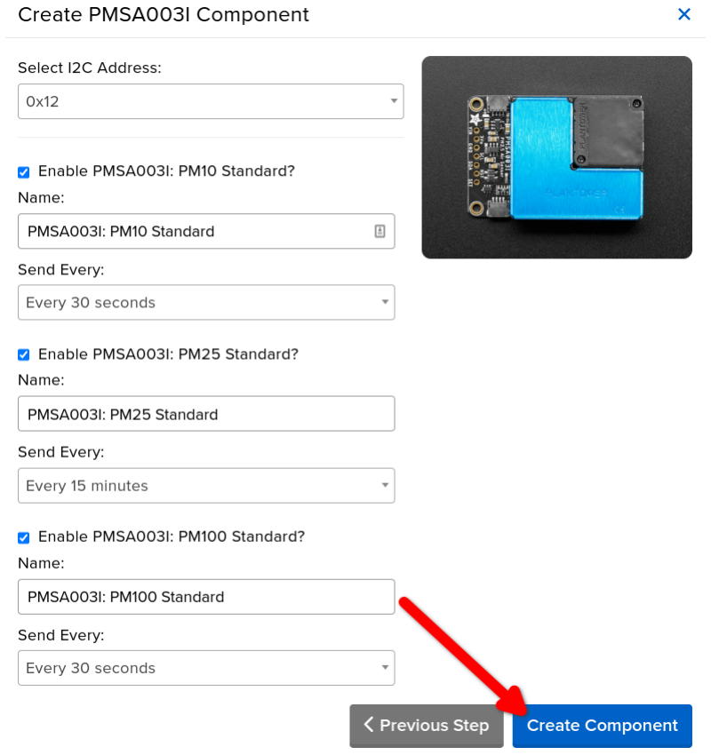
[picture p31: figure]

Your device interface should now show the sensor components you created. After the interval you configured elapses, WipperSnapper will automatically read values from the sensor(s) and send them to Adafruit IO.

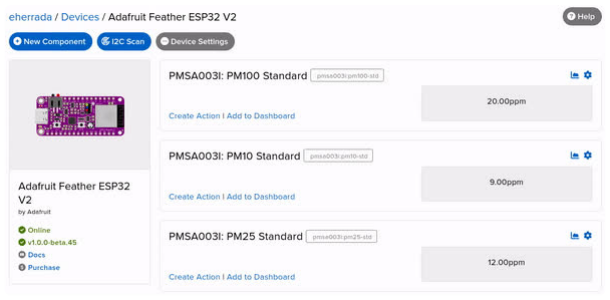
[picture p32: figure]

To view the data that has been logged from the sensor, click on the graph next to the sensor name.

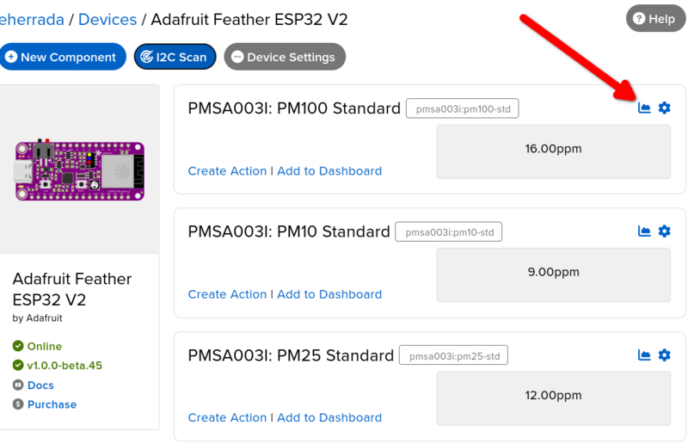
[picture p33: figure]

Here you can see the feed history and edit things about the feed such as the name, privacy, webhooks associated with the feed and more. If you want to learn more about how feeds work, check out this page (https://learn.adafruit.com/all-the-internet-of-things-episode-four-adafruit-io/advanced-feeds) (https://adafru.it/10aZ).
The PMSA003I sensor reads data and optionally categorizes it into PM1.0, PM2.5, and PM10.0 bins. Each bin has its own feed on Adafruit IO. In this picture, we're looking at the PM100 readings, but if you click on the graph icon for the different sensors you'll see their feed history.

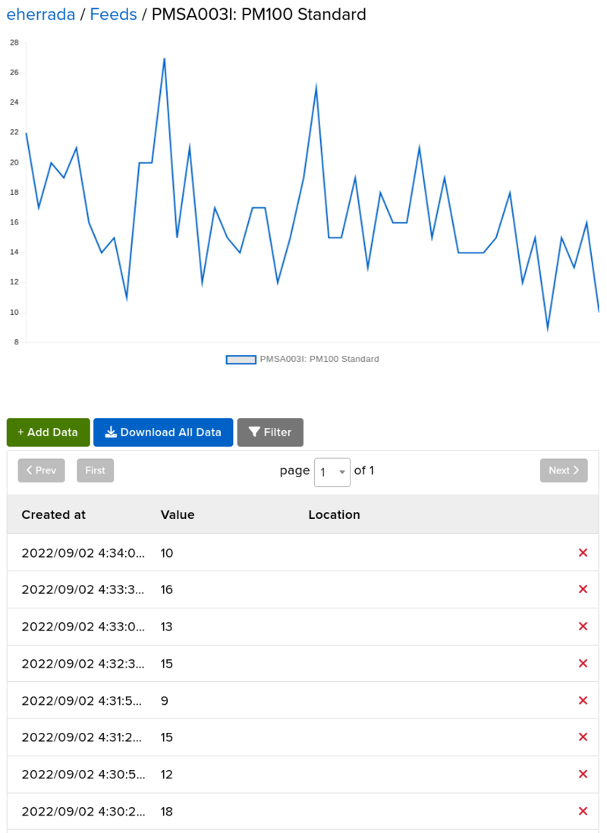
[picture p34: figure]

For IO Free accounts, feed data is stored for a maximum of 30 days and there's a maximum of 10 feeds. In this guide, you created three feeds (one for each of the PMSA003I's sensors). If you’d like to store data for more than 30 days, increase the number of feeds (components) you can use with WipperSnapper, or increase your data rate to send more sensor measurements to Adafruit IO - upgrade your account to Adafruit IO Plus (https://io.adafruit.com/plus) (https://adafru.it/Eg3).

# Downloads

## Files

PMSA003I datasheet (https://cdn-shop.adafruit.com/product-files/4632/4505_PMSA003I_series_data_manual_English_V2.6.pdf) (http://adafru.it/4632450500326) EagleCAD files on GitHub (https://github.com/adafruit/Adafruit-PMSA003I-PCB) (https://adafru.it/Mb3)
3D Models on GitHub (https://github.com/adafruit/Adafruit_CAD_Parts/tree/master/4632%20PMSA003I) (https://adafru.it/ODr)
Fritzing object in Adafruit Fritzing Library (https://github.com/adafruit/Fritzing-Library/blob/master/parts/Adafruit%20PMSA003I%20Air%20Quality%20Breakout.fzpz) (https://adafru.it/Mb4)

•
•
•
•

# Schematic

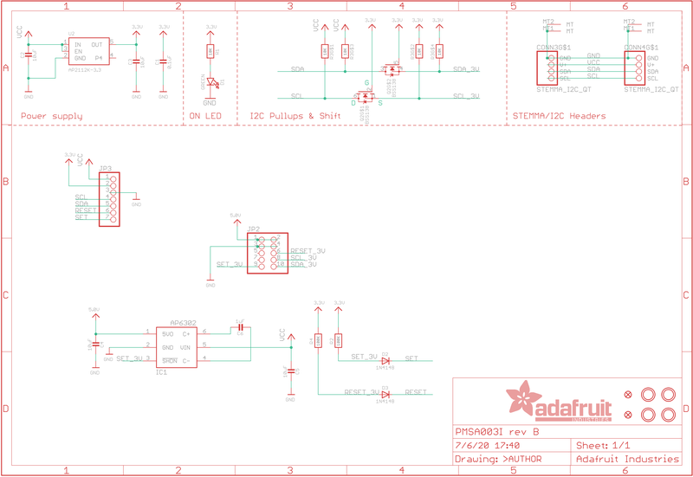
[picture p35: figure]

# Fab Print

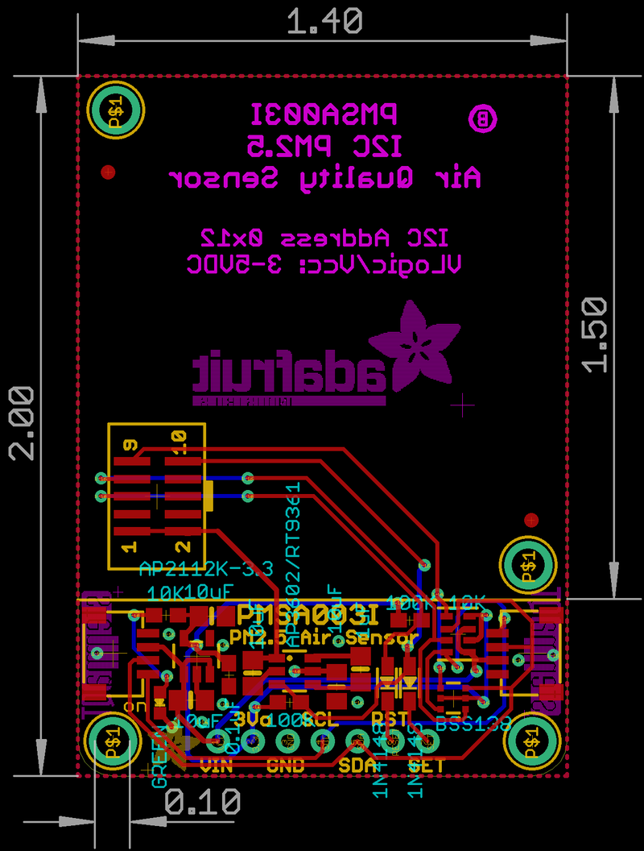
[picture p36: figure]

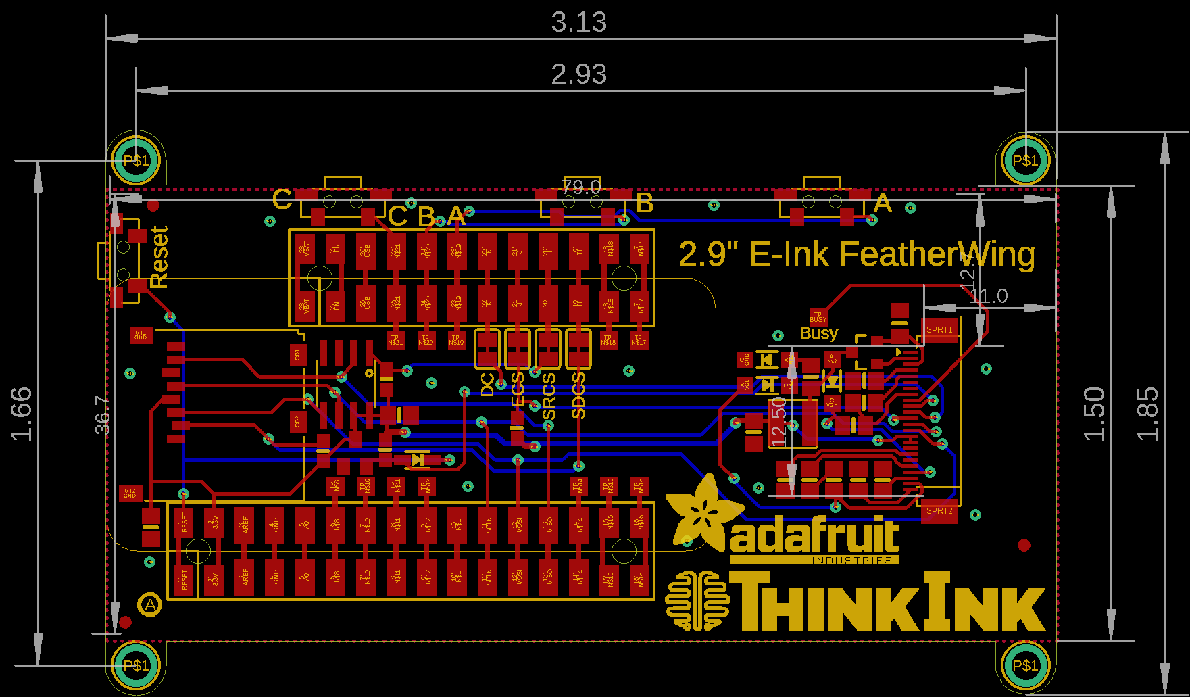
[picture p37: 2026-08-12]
docs/4777-eink-featherwing/featherwing-fab-print.png

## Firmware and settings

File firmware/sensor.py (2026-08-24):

import time

import board
import busio
import digitalio
from adafruit_pm25.i2c import PM25_I2C


def _median_sample(readings):
    ranked = sorted(readings, key=lambda r: r["pm25 env"])
    return ranked[len(ranked) // 2]


class Sensor:
    """PMSA003I on STEMMA I2C2, power-gated by LDO2."""

    def __init__(self, start_on=False):
        self._ldo = digitalio.DigitalInOut(board.LDO2)
        self._ldo.switch_to_output(value=bool(start_on))
        self._i2c = None
        self._pm = None

    def power_on(self):
        self._ldo.value = True

    def power_off(self):
        self._pm = None
        if self._i2c is not None:
            try:
                self._i2c.deinit()
            except Exception:
                pass
            self._i2c = None
        self._ldo.value = False
        print("LDO2 off")

    def ldo_pin(self):
        """DigitalInOut for LDO2, still owned. Drive it low before preserve_dios."""
        return self._ldo

    def release(self):
        """Power down and free the LDO2 pin so halt can hold it low."""
        self.power_off()
        if self._ldo is not None:
            try:
                self._ldo.deinit()
            except Exception:
                pass
            self._ldo = None

    def read(self, warmup_s, samples=3, stay_on=False):
        """Warm up, take samples. Power down unless stay_on (USB / development)."""
        cold = self._pm is None
        if cold:
            if not self._ldo.value:
                self.power_on()
            print("PM25 warmup {}s...".format(warmup_s))
            time.sleep(warmup_s)
            try:
                self._i2c = busio.I2C(board.SCL2, board.SDA2, frequency=100000)
                self._pm = PM25_I2C(self._i2c, None)
            except Exception as exc:
                print("PM25 init failed:", exc)
                self.power_off()
                return None

        readings = []
        attempts = samples + 8 if cold else samples + 2
        for i in range(attempts):
            try:
                readings.append(self._pm.read())
            except RuntimeError as exc:
                if cold and i < 6:
                    print("PM25 still starting...")
                else:
                    print("PM25 read failed:", exc)
            if len(readings) >= samples:
                break
            time.sleep(1)

        if not stay_on:
            self.power_off()
        if not readings:
            return None
        return _median_sample(readings)

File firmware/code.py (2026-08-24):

import time

import board
import digitalio

import aqi
import battery
import config
import display_ui
import persist
import power
import sensor as sensor_mod
import vlog

_MIN_EINK_S = 30


def _now():
    try:
        return time.time()
    except Exception:
        return int(time.monotonic())


def _buttons():
    pins = []
    for name in (board.D11, board.D12):
        pin = digitalio.DigitalInOut(name)
        pin.switch_to_input(pull=digitalio.Pull.UP)
        pins.append(pin)
    return pins


def _pressed(pin):
    return not pin.value


def _release_pins(pins):
    for pin in pins:
        try:
            pin.deinit()
        except Exception:
            pass


def _pack(reading, bat, usb, page, stale, sampled_at):
    state = {
        "page": page,
        "stale": stale,
        "usb": usb,
        "sampled_at": sampled_at,
        "percent": bat.get("percent") if bat else None,
        "voltage": bat.get("voltage") if bat else None,
        "present": bat.get("present") if bat else False,
        "charge_rate": bat.get("charge_rate") if bat else None,
        "charge_label": bat.get("charge_label") if bat else None,
        "aqi": None,
        "short": None,
        "category": None,
        "pm25": None,
        "pm10": None,
        "pm1": None,
    }
    if reading:
        pm25 = reading.get("pm25 env")
        converted = aqi.from_pm25(pm25)
        state.update(converted)
        state["pm10"] = reading.get("pm100 env")
        state["pm1"] = reading.get("pm10 env")
        for _label, key in aqi.PARTICLE_BINS:
            state[key] = reading.get(key)
    return state


def _rounded(value):
    if value is None:
        return None
    return int(round(float(value)))


def _card_key(state):
    """Visible eInk fields; ignore age so a stable reading does not flash the panel."""
    return (
        state.get("page", 0),
        bool(state.get("low_batt")),
        bool(state.get("usb")),
        state.get("aqi"),
        state.get("short"),
        _rounded(state.get("pm1")),
        _rounded(state.get("pm25")),
        _rounded(state.get("pm10")),
        _rounded(state.get("percent")),
        state.get("charge_label"),
        bool(state.get("stale")),
    )


def _should_refresh(previous, current, force, now):
    if force:
        return True
    if previous is None or previous.get("refreshed_at") is None:
        return True
    if _card_key(previous) != _card_key(current):
        return True
    return (now - previous.get("refreshed_at", now)) >= config.MAX_STALE_REFRESH_S


def _sample_interval(usb):
    if usb:
        return config.USB_SAMPLE_INTERVAL_S
    return config.SAMPLE_INTERVAL_S


def _keep_sensor_on(usb):
    return config.keep_sensor_powered(_sample_interval(usb))


def _sample(sensor, usb, page):
    stay_on = _keep_sensor_on(usb)
    print("Sampling PM sensor (LDO2 {} between reads)...".format("stays on" if stay_on else "off"))
    reading = sensor.read(
        config.SENSOR_WARMUP_S, config.SENSOR_SAMPLES, stay_on=stay_on
    )
    bat = battery.read()
    now = _now()
    stale = reading is None
    if stale:
        print("No sensor reading")
        saved = persist.load() or {}
        saved["stale"] = True
        saved["usb"] = usb
        saved["page"] = page
        saved["percent"] = bat.get("percent")
        saved["voltage"] = bat.get("voltage")
        saved["present"] = bat.get("present")
        saved["charge_rate"] = bat.get("charge_rate")
        saved["charge_label"] = bat.get("charge_label")
        saved["age_s"] = None if saved.get("sampled_at") is None else now - saved["sampled_at"]
        vlog.append(saved, _sample_interval(usb))
        return saved
    state = _pack(reading, bat, usb, page, False, now)
    print(
        "PM1.0={} PM2.5={} PM10={} ug/m3 AQI={} {} bat={} V={}{}".format(
            state.get("pm1"),
            state.get("pm25"),
            state.get("pm10"),
            state.get("aqi"),
            state.get("short"),
            state.get("percent"),
            state.get("voltage"),
            (" " + state["charge_label"]) if state.get("charge_label") else "",
        )
    )
    vlog.append(state, _sample_interval(usb))
    return state


def _show(display, state, previous, force, now):
    if state.get("sampled_at") is not None:
        state["age_s"] = now - state["sampled_at"]
    if not _should_refresh(previous, state, force, now):
        print("Skip eInk refresh")
        persist.save(state)
        return state
    print("Refreshing eInk...")
    display_ui.draw_card(display, state)
    display_ui.refresh(display)
    state["refreshed_at"] = now
    persist.save(state)
    return state


def _battery_is_low(bat):
    voltage = bat.get("voltage")
    if voltage is None:
        return False
    return voltage <= config.LOW_BATTERY_V


def _halt_low_battery(display, sensor, saved, bat, reason):
    if battery.usb_connected():
        print("USB in, skip halt")
        return
    sensor.release()
    ldo = power.claim_ldo2_off()
    state = saved if saved else {}
    state["low_batt"] = True
    state["usb"] = False
    state["present"] = True
    state["voltage"] = bat.get("voltage")
    state["percent"] = bat.get("percent")
    print(
        "Low battery {:.2f} V (wake {}) — showing halt card".format(
            bat.get("voltage") or 0, reason
        )
    )
    _show(display, state, None, True, _now())
    vlog.append(state, _sample_interval(False))
    power.halt_until_usb(config.LOW_BATTERY_SLEEP_S, ldo_pin=ldo)


def _sleep_between_samples(sensor, buttons, seconds):
    """deep/light: LDO2 off, sleep until timer, A, B, or USB plug."""
    _release_pins(buttons or ())
    sensor.power_off()
    hold = (sensor.ldo_pin(),) if config.use_deep_sleep() else None
    power.sleep_interval(
        seconds,
        config.use_deep_sleep(),
        preserve_dios=hold,
    )
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

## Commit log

2026-08-12 Add README, gitignore, and project BOM
2026-08-12 Initial commit: hardware docs and project notes.
    Adafruit/Unexpected Maker datasheets and learn guides for the FeatherS3[D], eInk FeatherWing, PMSA003I, STEMMA cables, and 400 mAh LiPo.
2026-08-12 Add CircuitPython firmware, bring-up script, and AQI tests.
    Host-tested EPA 2024 PM2.5 AQI conversion. Monitor firmware duty-cycles the PMSA003I on LDO2/I2C2, draws a 4-gray eInk card, and deep-sleeps on battery.
2026-08-12 Rewrite README with project writeup and Adafruit product photos.
    Drop the unused 50 mm STEMMA docs; the build uses the 100 mm cable.
2026-08-19 Tolerate PMSA003I warmup checksums and USB read-only CIRCUITPY.
    Keep the sensor powered in USB mode, cache last sample in RAM when the host has the drive mounted, and hide a 0% gauge reading unless a LiPo is actually present.
2026-08-19 Show PM1.0/PM2.5/PM10 on the eInk footer and refresh every 30s on USB.
    Reuse a single MAX17048 instance so the fuel gauge is not reset (and zeroed) on every sample.
    [battery.py, code.py, config.py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]
2026-08-19 Skip eInk full refresh when the card has not changed.
    4-gray SSD1680 updates must invert the panel; flashing every 30s was unnecessary when PM/AQI/battery text is unchanged.
    [code.py, display_ui.py]
2026-08-19 Treat USB-with-no-cell fuel-gauge readings as invalid.
    SOC over 100% is the charger node, not a LiPo. Hide it, quick-start when a pack is seated, flip the AQI needle to white on dark bar segments, and label the B-button page switch.
    [battery.py, code.py, display_ui.py]
2026-08-19 Redraw immediately on button B; cut LDO2 between long-interval samples.
    Page flips no longer wait for the next PM reading. The PMSA003I stays powered only when the sample period is under 60 s; battery (and USB at 5 min) drop I2C2 between reads. Skip MAX17048 quick-start on timer wakes.
    [battery.py, code.py, config.py]
2026-08-21 Halt at 3.2 V into deep sleep; battery sample 60 s with 5 s warmup.
    The Feather cannot software-latch EN, so low-battery is deep sleep until USB. LDO2 stays off between 60 s samples.
2026-08-21 Add a two-piece 3D-printed enclosure for the Feather/eInk/sensor stack.
    Base has USB-C, battery corral, wing pins, sensor posts and airflow slots.
    Lid has the 2.9\" window and sensor vents. STLs plus a parametric generator.
    [aq_enclosure_base.stl, aq_enclosure_lid.stl]
2026-08-21 Add SLEEP_MODE deep vs light, and force Wi-Fi/BLE off.
    Low-battery halt still uses deep sleep. Radios are disabled in boot.py and again before each sleep.
2026-08-24 Add CSV voltage/PM logging, unify the run loop, and tidy firmware.
    SLEEP_MODE is deep/light/no/full on USB and battery. Halt holds LDO2 off.
    Logs go to data/voltN.csv with monotonic elapsed time. USB footer tracks VBUS.
    Cleanup: drop unused PM25_REFRESH_DELTA, one PARTICLE_BINS list in aqi.py,
    and stop disabling radios again at code.py start (boot.py still does it;
    power.disable_rf remains before sleep).
2026-09-04 Redesign enclosure: 1\" stack, 1/2\" battery cage, dual lid-mount, RP-SMA, split airflow.
    Mounting and air ports print filled with raised drill rings. Sensor ridge is 9/16\" over the can. USB-C is a real opening on the bottom wall.
    [aq_enclosure_base.stl, aq_enclosure_lid.stl]
2026-09-04 Size the battery cage for a 2\" x 1-5/16\" x 3/8\" pack.
    [aq_enclosure_base.stl]
2026-09-04 Replace the AQI roof with a short lip over the air channel.
    The 9/16" piece now overlaps the can by 3.5 mm and roofs the intake/exhaust
    plenum only. Print the base with slicer supports under those overhangs.
    [aq_enclosure_base.stl]
2026-09-04 Mount the AQI module on the floor with a bottom-side cable pass.
    STEMMA notch moves to the USB end of the display. Sensor holes match the
    Adafruit board: two open header holes screw down from inside, two under-can
    holes drill from the outside and screw up.
    [aq_enclosure_base.stl, aq_enclosure_lid.stl]
2026-09-04 Align AQI holes and the in/out divider with the fan.
    The 2" axis points away from the display so two corner holes sit on the
    top edge. The intake/exhaust split stays on that top wall, 7/8" from the
    far end.
    [aq_enclosure_base.stl, aq_enclosure_lid.stl]
2026-09-04 Tighten the enclosure lid and AQI bay around the real parts.
    Lid opening is the 79 x 36.7 mm e-ink module with corner tabs for the
    holes. AQI is Y-centered on the display; USB-C is lid-off only. Bottom
    lip sits on the module edge and stops short of the STEMMA holes.
    [aq_enclosure_base.stl, aq_enclosure_lid.stl]
